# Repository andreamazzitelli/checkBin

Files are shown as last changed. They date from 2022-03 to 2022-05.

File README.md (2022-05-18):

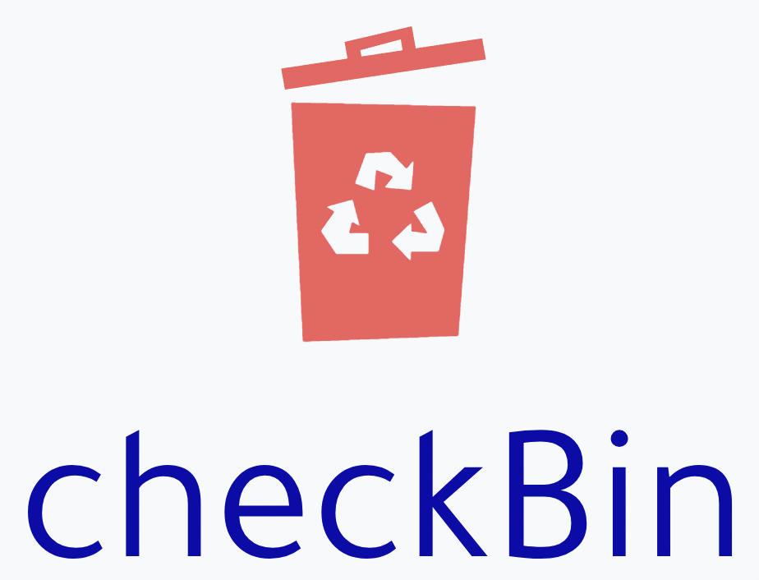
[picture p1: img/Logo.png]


## Group Members:

- Alessandro Marzilli - [LinkedIn Profile](https://www.linkedin.com/in/alessandro-marzilli-84a07a235/)
- Andrea Mazzitelli - [LinkedIn Profile](https://www.linkedin.com/in/andrea-mazzitelli-795ab4234/)
- Andrea Rodriguez - [LinkedIn Profile](https://www.linkedin.com/in/andrea-rod/)

## Description of the Project:

Today a big issue in many cities is garbage management, not only from an aesthetical point of view but also regarding administration and logistics costs. For this reason we envisioned a network of smart bins that monitor the fill level and give updates on their status. In this way the garbage pickup companies can have an overall view of the real-time situation and act accordingly. They could plan efficient pickup routes based on the fill level of the bins, manage the number of bins in each area and base their decisions on statistical analysis of provided data. As a consequence not only the company’s resources are used in a more efficient way but also the urban welfare increases thanks to less garbage on the streets and increased usability of the bins.

## Prototype:
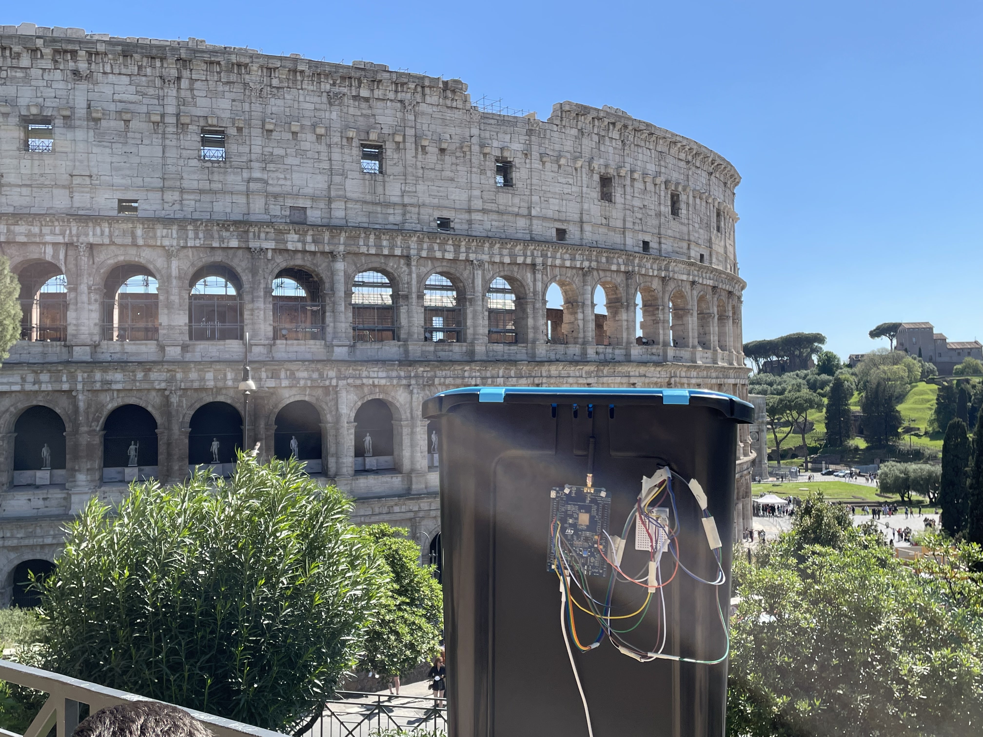
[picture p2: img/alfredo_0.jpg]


## Blogpost:
- [Link to hackster](https://www.hackster.io/463097/checkbin-439d2e)

## Documents:
### Third delivery:
- [Concept](/doc/Third%20Delivery/Concept.md)
- [Technology](/doc/Third%20Delivery/Technology.md)
- [Evaluation](/doc/Third%20Delivery/Evaluation.md)
### Second delivery:
- [2nd Delivery](/doc/Second%20Delivery/2ndDelivery.md)
- [Concept](/doc/Second%20Delivery/Concept.md)
- [Technology](/doc/Second%20Delivery/Technology.md)
- [Evaluation](/doc/Second%20Delivery/Evaluation.md)
### First delivery:
- [Concept](/doc/First%20Delivery/Concept.md)
- [Technology](/doc/First%20Delivery/Technology.md)
- [Evaluation](/doc/First%20Delivery/Evaluation.md)

## Videos:
### Third delivery:
- [Presentation of the project](https://youtu.be/aXUBlsJxcLs)
- [Demonstration of the project](https://youtu.be/RxiEFSnZMP0)
### Second delivery:
- [Technical details](https://youtu.be/C8MtbwdandU)
- [Evaluation](https://www.youtube.com/watch?v=46vqiiF-4S0)
- [Future plans](https://www.youtube.com/watch?v=kTAaOJ-Nj90)
### First delivery:
- [Concept](https://youtu.be/G0L1xYLjtnY)
- [Technology](https://youtu.be/uhQEX0K4BaE)
- [Evaluation](https://youtu.be/skyZr8n79Us)

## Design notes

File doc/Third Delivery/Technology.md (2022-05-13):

# TECHNOLOGY

## General Architecture

The computation is carried both on the edge and in the cloud. Every board will compute the fill level through the data coming in from the sensors and will send only this refined value to the cloud when it changes. The cloud will generate a dashboard with a map of the city combining the data received together with the database which links every bin identifier to its location. This dashboard will be publicly available through http both to the garbage collection company and to the citizens.

## Bin Overview

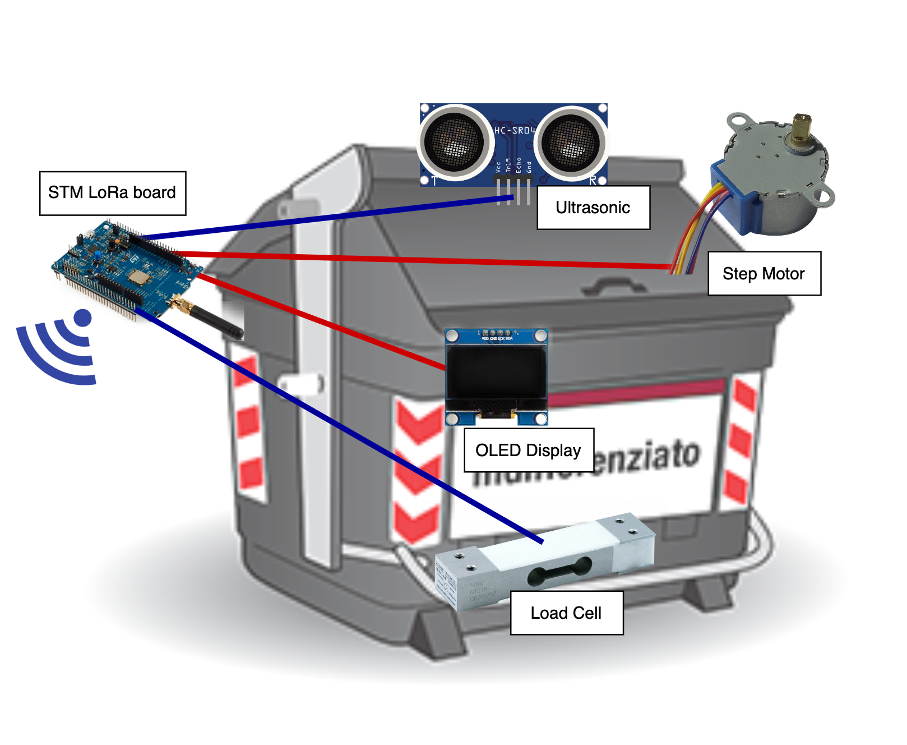
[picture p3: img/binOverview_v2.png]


Every smart bin is equipped with:

***LoRaWAN compatible STM board***

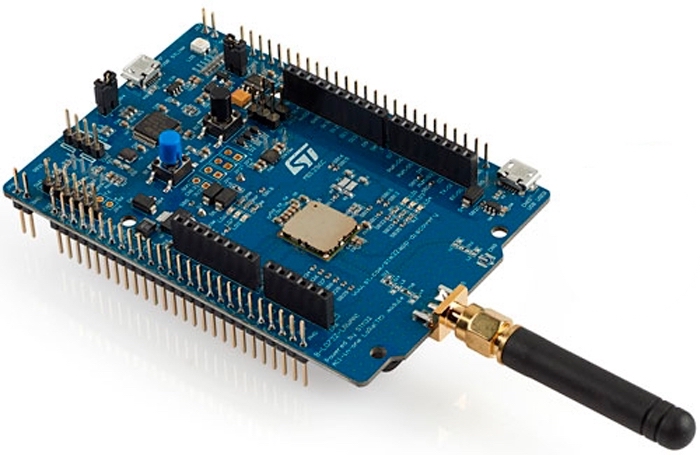
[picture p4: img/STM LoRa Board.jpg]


STM32L0 Discovery kit LoRa, Sigfox, low-power wireless. The module is powered by an STM32L072CZ microcontroller and SX1276 transceiver. The transceiver features the LoRa long-range modem, providing ultra-long-range spread-spectrum communication and high interference immunity, minimizing current consumption.
In the cities there should be some LoRaWAN gateways to pick up all the signals sent by the bins.
We used LoRa as communication protocol between the Smart bins and TheThingsNetwork. Using the integration between TheThingsNetwork and AWS IoTCore we receive the messages in the broker provided by AWS.
To allow the communication the following parameters must be set in the main.h file: dev_eui, app_eui, app_key. 

***Ultrasonic sensors*** to measure occupied volume in the bin.

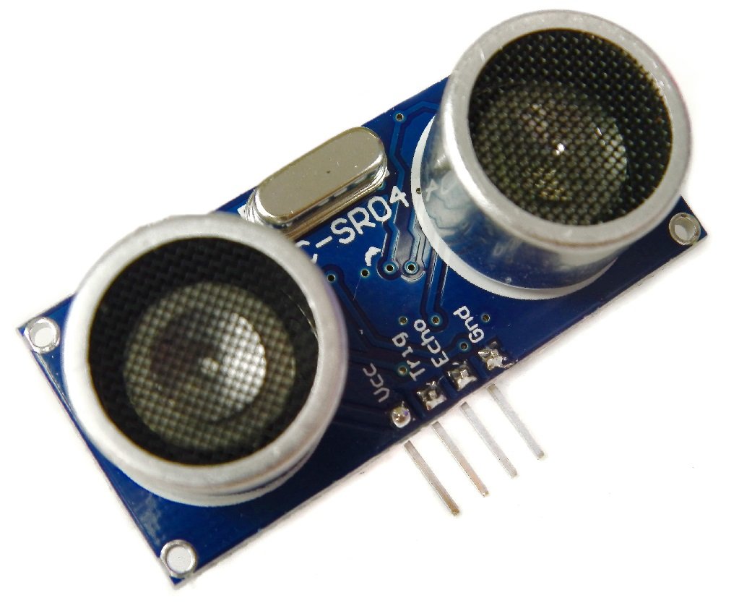
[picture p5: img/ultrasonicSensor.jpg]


We use ultrasonic sensors as the main way of measuring the fill level of the bins. In the prototype we used only one sensor but we decided to take three measures every time with a 30 seconds timeout. In this way we can discard measurements taken while the bin was open. Using more ultrasonic sensors would enhance the accuracy of the measures but implies a linear increase in the energy consumption of the sensors of the whole system.

***Load cells and a Load Cell Amplifier*** to measure the weight of the trash in the bin.

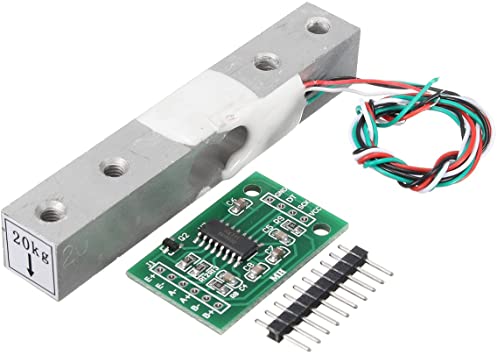
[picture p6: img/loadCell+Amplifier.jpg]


To detect anomalies in the data read by ultrasonic sensors we use a load cell. Together with statistics based on gathered data we can compare the occupied volume in the bin and the weight to understand if there is an anomaly in the ultrasonic measure. To estimate the weight based on the ultrasonic measure and to estimate the maximum weight, the following parameters must be set in the main.h file: height of the bin in cm, base area of the bin in square meters, waste type (plastic, metal, glass, paper, food, mixed).

To convert the value read from the load cell into grams we tested it using different weights. We then analyzed the measurements and discovered a linear pattern. Consequently, to convert the value returned from the load cell we must subtract it from the base value (8500 in our case) and divide it by 0.104.

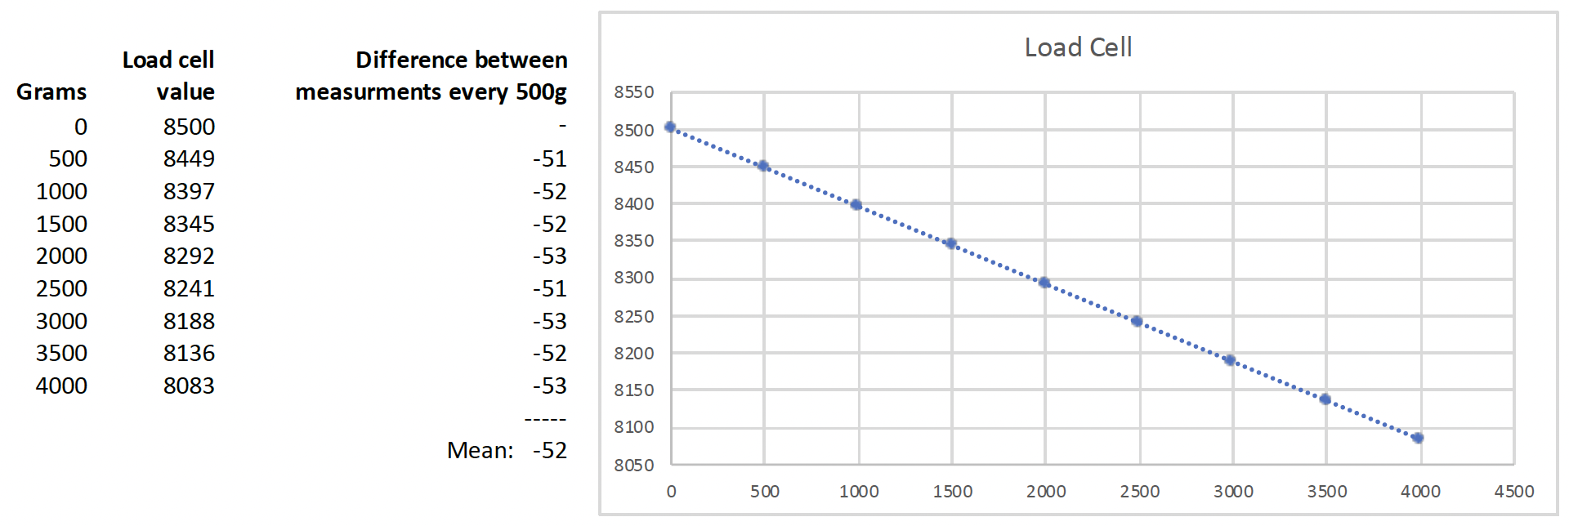
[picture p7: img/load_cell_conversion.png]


***Button*** to open the bin when it is locked.

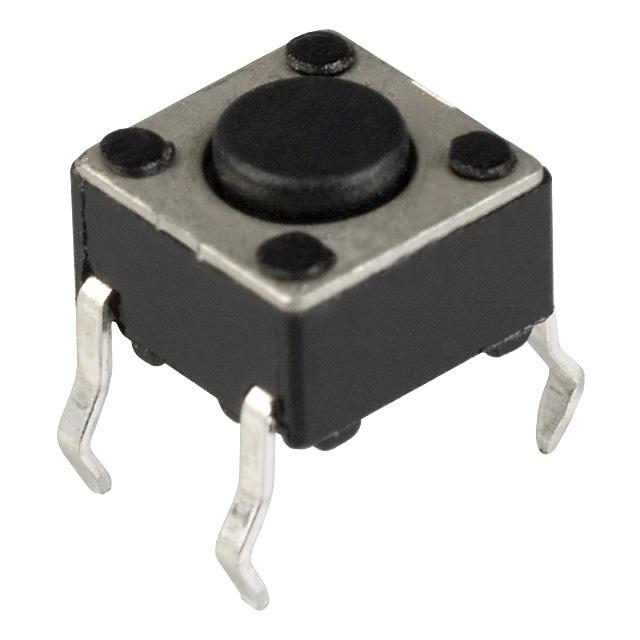
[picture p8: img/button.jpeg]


***OLED Display*** to show the fill level to the citizens.

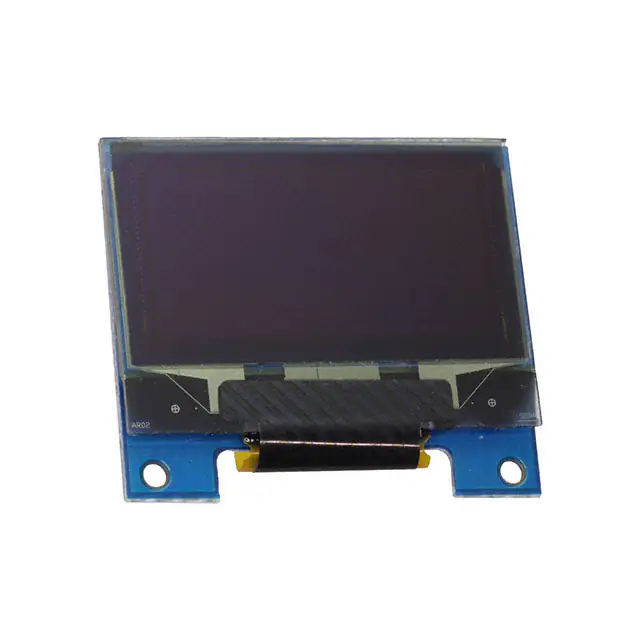
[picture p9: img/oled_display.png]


The OLED Display provides information about the fill level as feedback to the citizens. It shows a numeric value together with the progress bar. In this way they can be more involved in the process and take responsibility. 

***Stepper motor*** to lock the opening of the bin when it is full and to unlock it when it gets emptied.

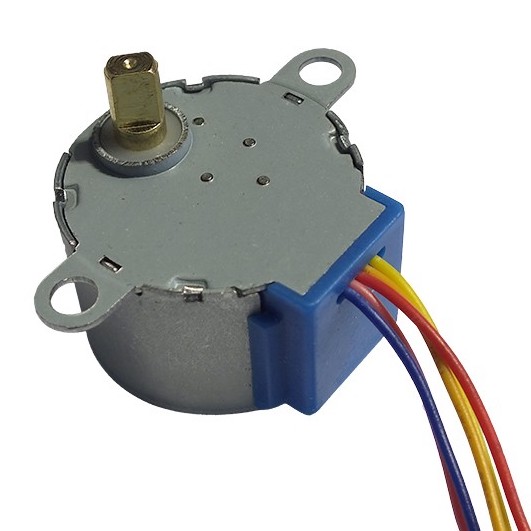
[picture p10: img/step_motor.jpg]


### All the components are wired following the diagram below:

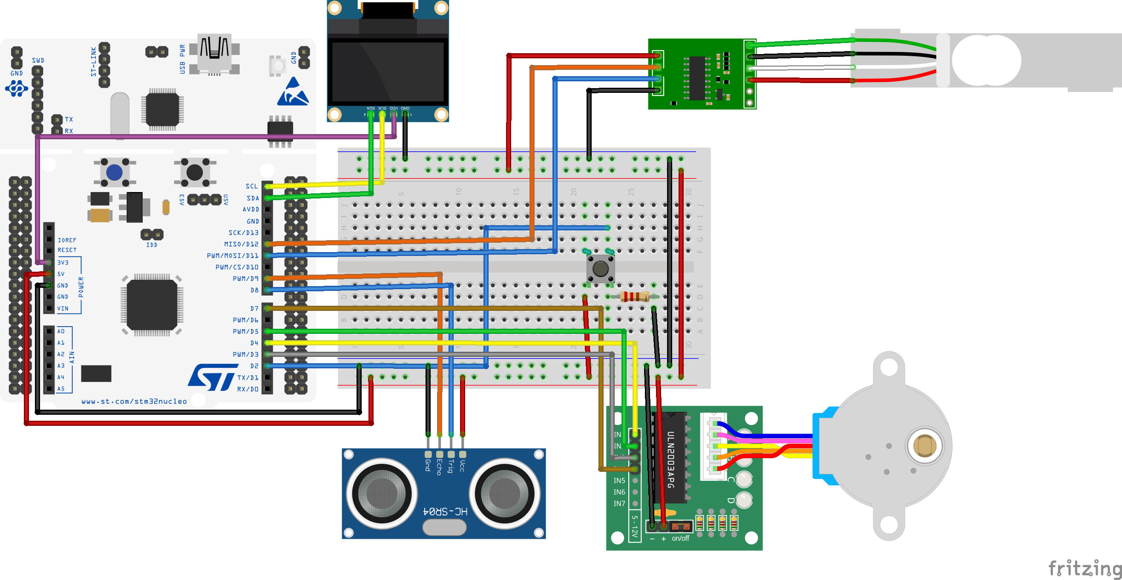
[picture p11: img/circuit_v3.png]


## The prototype

To see first hand how our system would be implemented on a real bin, we built a prototype. Starting from a standard bin we used hot glue and some 3D printed parts to put on the bin: sensors, actuators and the board.
We used a different kind of bin from the one shown in the overview. That is because of the unavailability of a standard garbage bin in this first development phase. However, the system we built is easily adaptable to different kinds of bins.
What you can see in these photos is the final result:

<div>
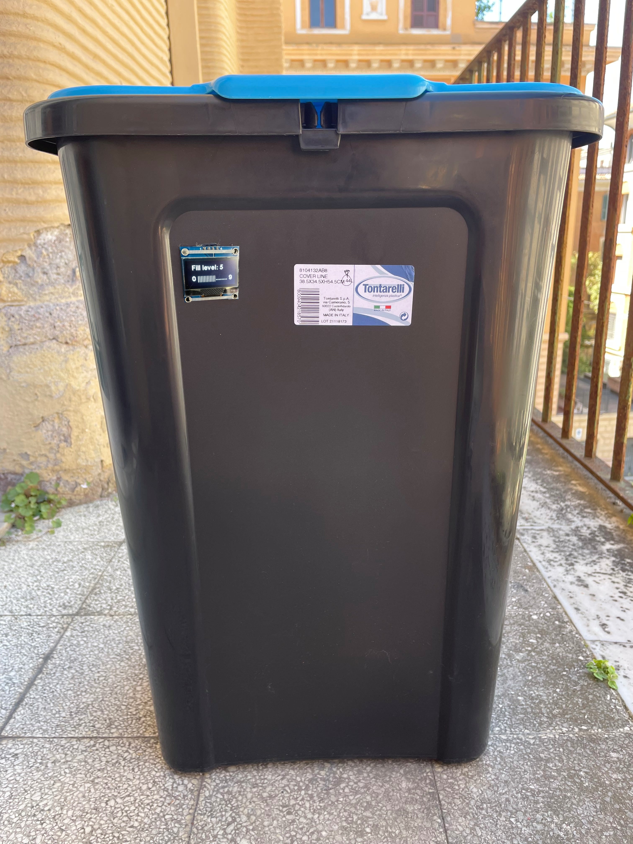
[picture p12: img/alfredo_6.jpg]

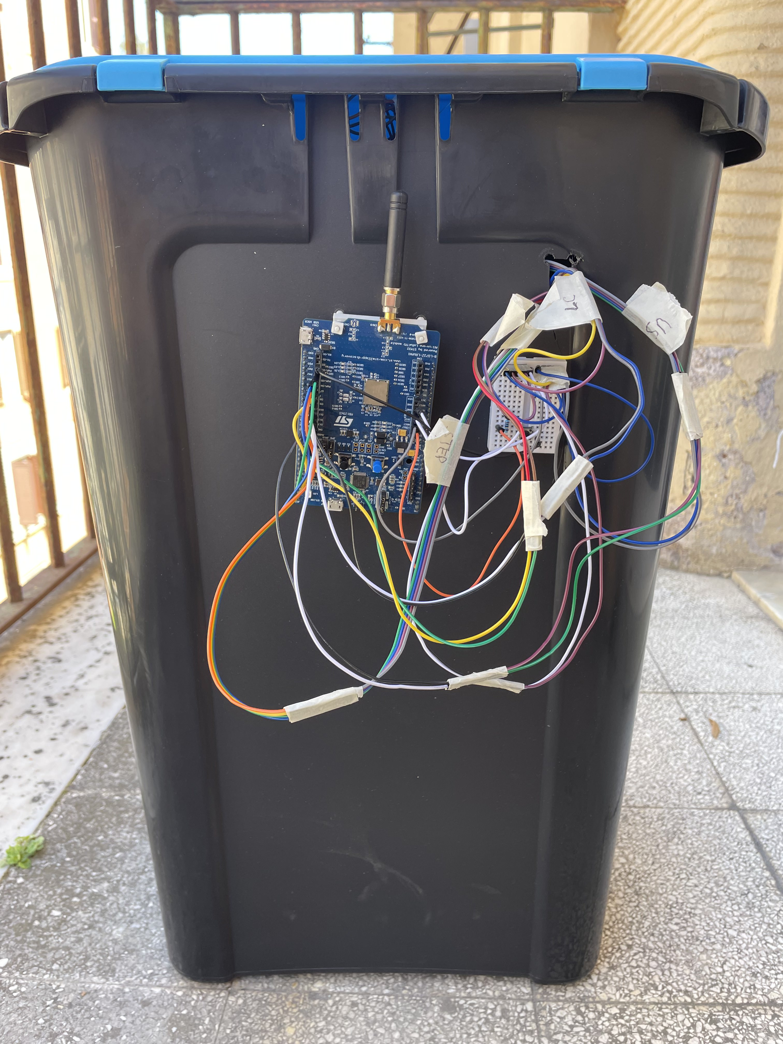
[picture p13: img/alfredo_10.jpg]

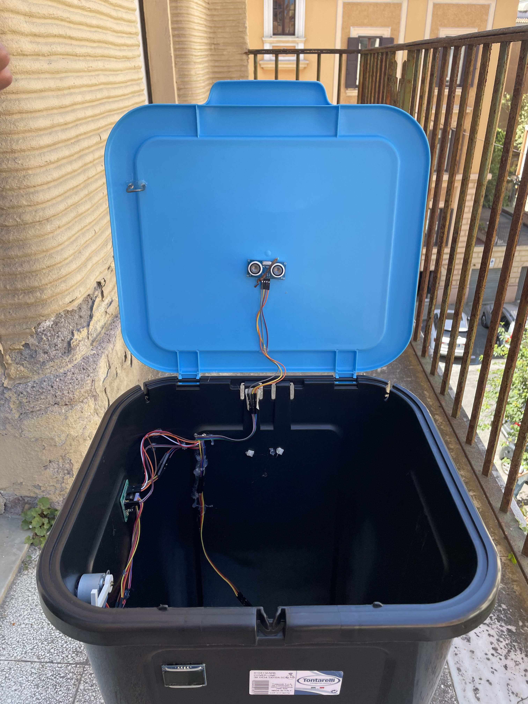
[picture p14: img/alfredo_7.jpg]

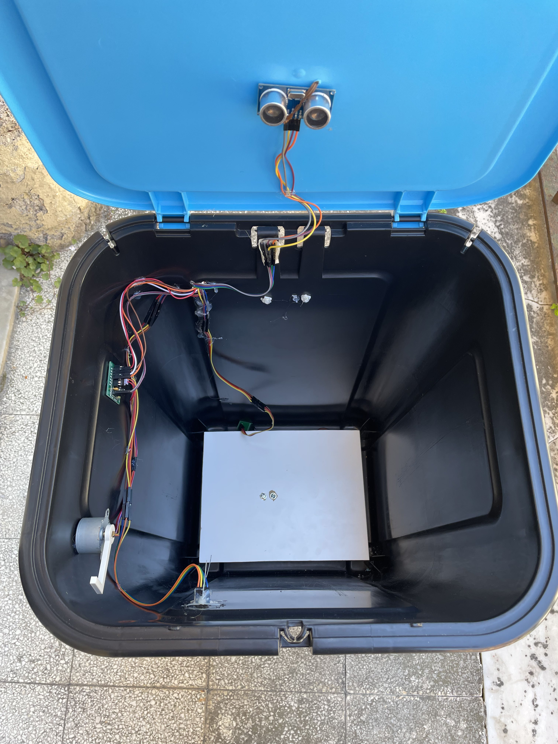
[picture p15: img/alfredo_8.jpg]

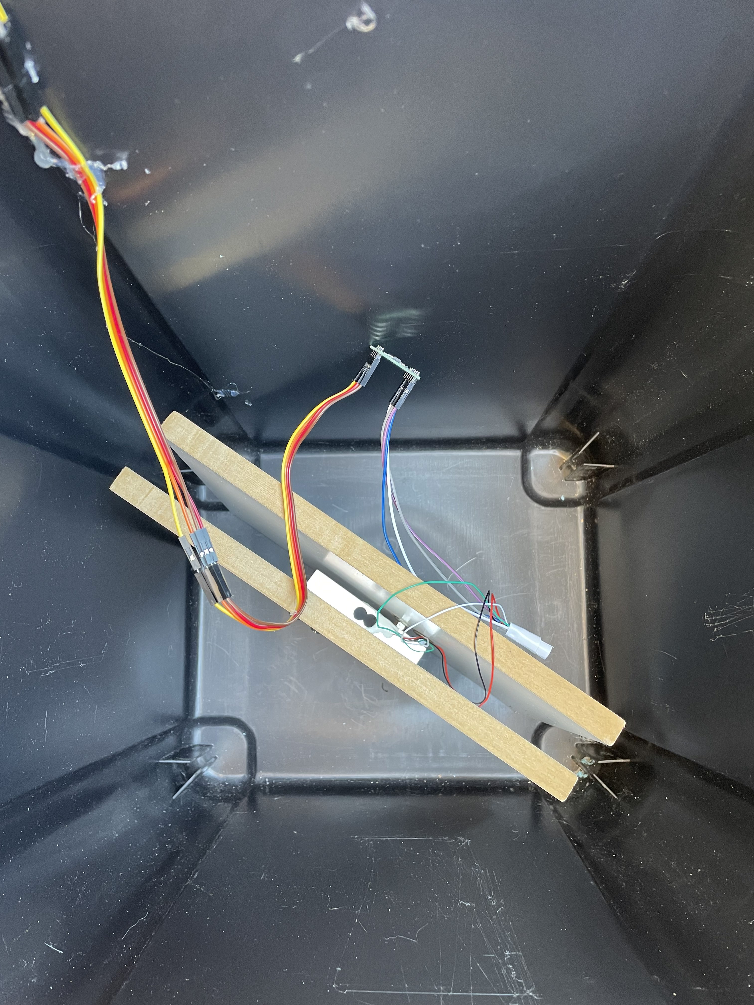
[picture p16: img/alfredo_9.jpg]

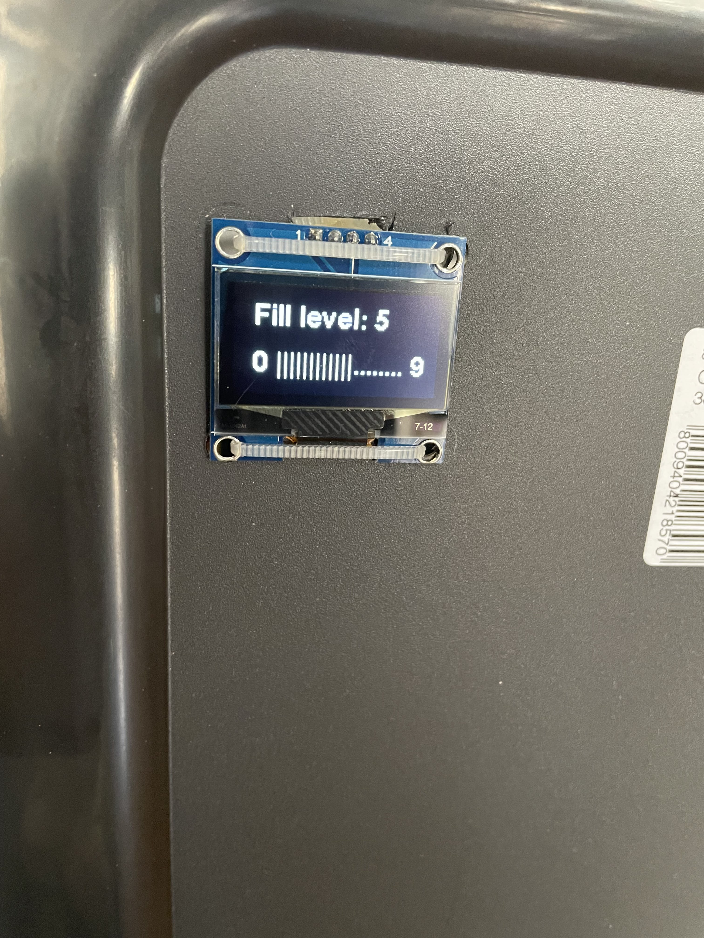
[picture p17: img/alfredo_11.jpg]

</div>

## Logic
The RIOT code implements the logical computation carried out in the LoRa board. In the main function it initializes the sensors, the actuators and the LoRa communication parameters.
It then starts a loop which alternates an active phase and a sleeping phase.

In the active phase the code does the following:
- the ultrasonic sensor makes three measurements with a 30 seconds timeout
- among the three values it rules out eventual anomalies and choose the pertinent one
- it then converts it to a fill level between 0 and 9 knowing the height of the bin
- the load cell is used to get the weight of the trash inside the bin
- based on the fill level and the type of garbage, it computes the estimated weight
- it also computes the maximum weight based on the height of the bin, the base area and the type of garbage

- if the fill level is lower than 8 but the weight is more than the maximum one (with a 20% margin) we have an anomaly; it sends to the cloud a fill level of 9 to notify the bin must be emptied but it does not close the bin.
- else if the fill level has changed from the previous measurements it sends the fill level to the cloud and updates the values on the OLED display. Then it also checks:
  - if the weight is below the estimated one (with a margin of 20%) when the fill level is greater or equal than 8; in that case it keeps the bin open
  - else if the fill level is greater or equal than 8 and the weight is coherent, it closes the bin
  - else it opens the bin

Moreover a separate thread is used to handle the bin’s opening using the button:
- if the button is pressed and the bin is locked then it is unlocked.

### Accuracy of the fill level
The fill level is computed from the measures taken by the ultrasonic sensor. Its accuracy can be an issue since the sensor measures the distance of a small area of the bin.
<br>As a consequence it could happen that in this area there is a lot of trash while the remaining space is empty. For this reason we decided to take into consideration also the weight measured through a load cell to implement a double check measure.
<br>Indeed we verify if the real weight measured is similar to the estimated weight with a margin of 20 percent (computed by using the fill level of the bin, the base area and the waste type). This double check allows us to detect a mismatch between the two measurements and makes us aware of any anomaly in the system.

- An anomaly is detected when the fill level is greater or equal than 8 and the weight is lower than the estimated one. We decided not to close the bin (since the bin could be not really full) while still sending the fill level to the cloud. Because of the mismatch between the measurements of the two sensors, we do not really know if the bin is actually full or not. Indeed we prefer to leave the bin open during an anomaly even if it is actually full instead of closing it while it is still empty.
- Another anomaly could happen if the load cell returns a weight greater than the maximum one (with a margin of 20 percent) but the fill level is smaller than 8. Also in this case we decided to adopt the same policy as before, keeping the bin open and sending 9 as fill level to the cloud. In this way an operator will empty the bin and solve the anomaly.

Another solution is to add more ultrasonic sensors to the system; this solution would increase the cost in terms of power consumption but it would be more precise in detecting the fill level of the bin.

## Network

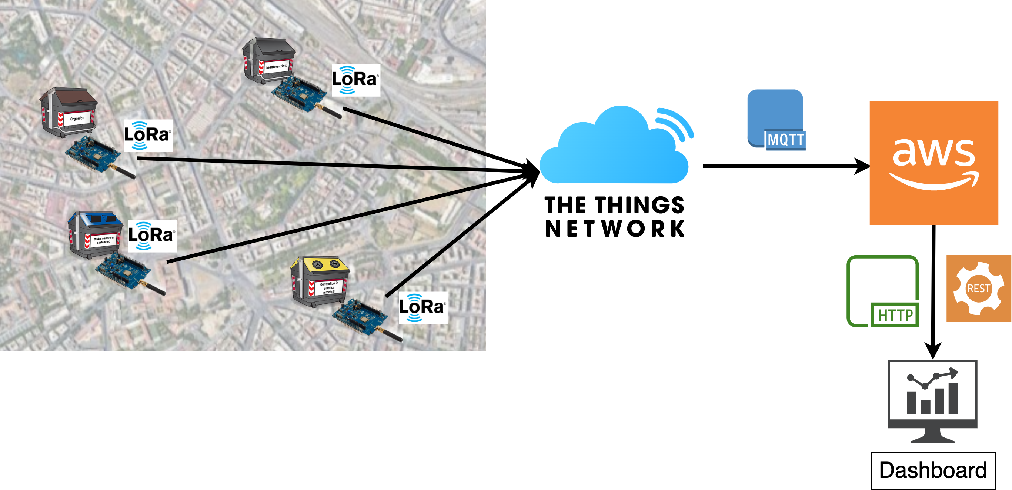
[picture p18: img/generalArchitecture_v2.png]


This architecture does not have any particular network constraint. We update the data on the cloud either when the fill level changes or when an anomaly is detected by the load cell. This choice has been made considering the nature of the system which only needs to know the last measured fill level.
We send to the cloud only the fill level of the bin, so the bandwidth needed by each device is minimal. Even though we take into account the great number of bins that even a small city has, the payload transmitted by each one is 1 byte every time the fill level changes (it should be no more than 10 times between two bin unloadings). Having planned a high update latency implies fewer usage of the radio that can be turned off during sleep times saving energy.

The security aspect is fulfilled by LoRa protocol which uses a double encryption to protect the payload from the source to the application server.

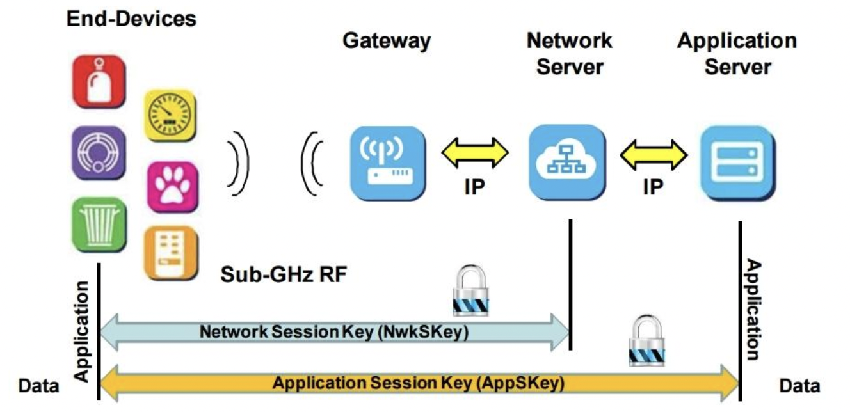
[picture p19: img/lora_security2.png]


*credits: https://riot-os.github.io/riot-course/slides/05-lorawan-with-riot/#12*

We ruled out every kind of communication directed to the board as it would need the radio always on. We couldn’t afford that in developing a battery powered device that needs to be up for at least a year without a constant power supply.
<br> We also considered structuring the network as a mesh to avoid the need of developing a gateway infrastructure. However, this approach would also require the radio to be always on but, as stated before, we cannot afford that.
<br> Different solutions must be researched to have a gateway infrastructure available. The garbage pickup company could develop its own infrastructure or it could use an existing infrastructure provided by some third party.

LoRa has been chosen as communication protocol because of its low power consumption and long range. Its main constraint is the low bitrate but it is still suitable for our project. WiFi and Bluetooth could provide higher bitrate but lower range, which is not ideal for our system. 3G/4G/5G could also provide not only higher bitrate and high range, but also an existing and wide gateway infrastructure. The main drawback of these technologies is the power consumption which is higher than the one we can support.

## Cloud

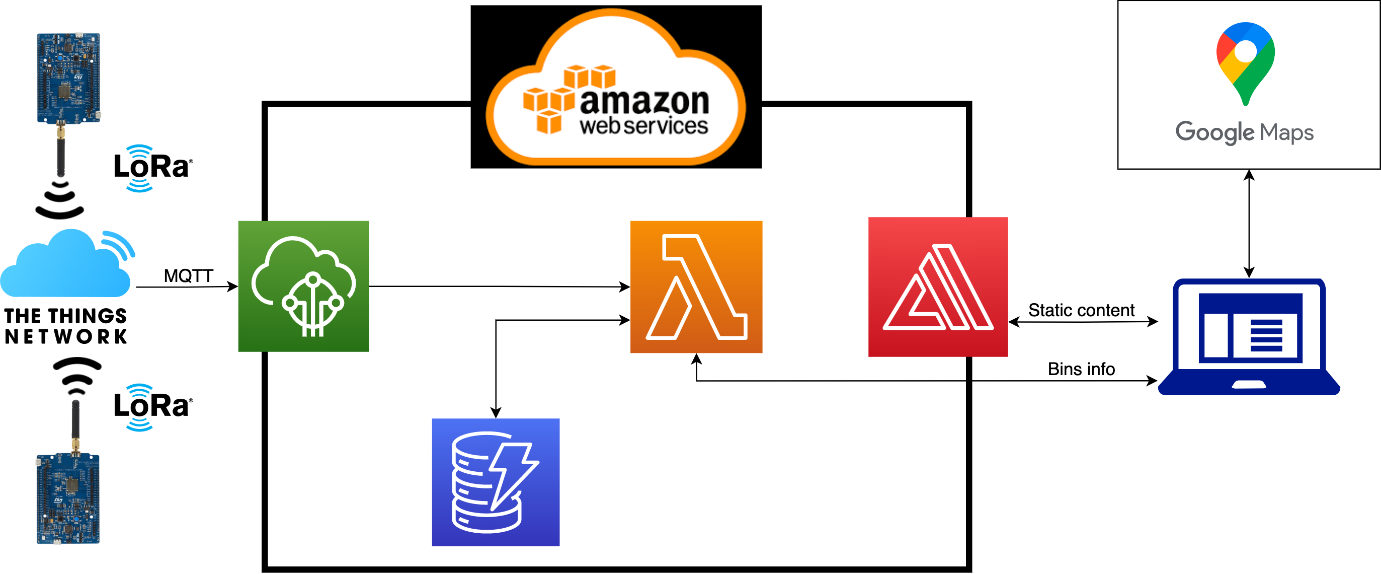
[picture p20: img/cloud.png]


The cloud part of the project is composed by the following elements:
- The Things Network
- AWS IoT Core
- AWS Lambda Function
- AWS DynamoDB
- AWS Amplify
- APIs provided by Google Maps.

The format of the messages sent from the board is the following: `fill_level`.

The DataBase is composed of a single table `binTable(DevEUI, id, lat, lng, last_fill_level, last_fill_timestamp)` in which:
- the DevEUI assigned to the device is used as primary key of the table; 
- id is used to identify the bin on the web dashboard;
- lat and lng are the geographic coordinates where the bin is located;
- last_fill_level is the last fill level received from the board;
- last_fill_timestamp is the timestamp at which the last fill level was received.

As the primary key of the table we decided to use the DevEUI assigned to each bin. In this way we can immediately associate the messages received to the respective bin using information that is automatically sent in the exchange, without the need to add more information in the message payload.
We also chose to use an ID to identify in a simpler way the bins in the web dashboard. Being the bins often one near the other, a garbage truck driver can use the ID to understand which bin needs to be emptied. Clearly, the id should be written on the physical bin. 

When a message containing the fill level is sent to a LoRa Gateway in The Things Networks (TTN), TTN relays the incoming message to the MQTT Broker in the AWS IoT Core.
Once the IoT Core receives a new message on the broker, using its Rule Engine, it calls the Lambda Function “writeBinTable_v2”. This function updates the tuple in the DB that has the DevEUI as the one in the message that just arrived.

The user interacts with AWS Amplify to get the static content. Once the page on the client browser completely loads, it runs the javascript code that generates the map with markers where bins are located. The user can now click a marker to see the bin id, the last fill level and the time when the last fill level was detected.
In particular, the js code does the following:
- it calls the Google Maps API to retrieve the map;
- it calls the Lambda function “getBin_v2” using the “Function URL” that returns all the tuples inside “binTable” ([here](https://docs.aws.amazon.com/lambda/latest/dg/lambda-urls.html) there is a description of what is a function URL);
- once the data arrives, for every bin the script adds a clickable marker containing all the info about the bin with a different color depending on the fill level;
- every 10 minutes the dashboards reloads, we chose not to update it in real time using websockets due to scalability concerns.

The web dashboard can be accessed [here](https://dev7723.d2wnn0xh1kb5op.amplifyapp.com/).

From the web interface the user can also add a new bin to the system by filling the latitude and longitude fields and clicking on the “Add Bin” button. It calls the function URL of the “addBin_v2” Lambda Function that creates a new tuple in “binTable” and returns to the user the new bin id.

Moreover the user can delete a bin from the system by inserting the id in the corresponding field and then clicking on the “Delete Bin” button. In this way the Lambda function “deleteBin” is called and the tuple associated with the specified bin’s id is deleted from the DB.

All the data stored in the database can also be reached via a REST API, to ease the integration with pre-existing management systems of the garbage pickup companies. You can call it from [here](https://slfosy6btrlq2u2xufldfoy5fi0reboc.lambda-url.us-east-1.on.aws/).

## Future plans for technology improvements:

### Edge computing
We could use the edge to run a machine learning algorithm which learn and adjust some relevant parameters like the interval between measurements or the specific weights of every waste type.
For both aspects we can consider different possibilities:
- using all global data coming from every bin, in this case gateways should be orchestrated to learn the global parameters. This option is the best one to learn the specific weights of waste types. Due to the facts that these parameters do not differs much among bins, using a global algorithm would allow us to have a bigger dataset that increases the accuracy of the model and produces better results.
- using all data received by a single gateway, in this way we would have neighbourhood specific parameters.
- using data coming from a single bin, in this way we would have specific parameters for every bin. This option is the best one to learn the interval between measurements. Indeed, regarding the fill rate and frequency of waste deliveries, each bin is mostly different from the others.

To achieve the proposed goals, edge computing is the best option because the boards do not have enough computational power or energy to run complex algorithms. Moreover the gateways already have the necessary data and can communicate with the boards to send the new parameters. Regarding a possible usage of the cloud, the measure interval is a parameter strictly related to a bin and it would not make sense sending parameters to the cloud to compute as there's no need to aggregate data.

### Replacing the OLED with a e-ink display

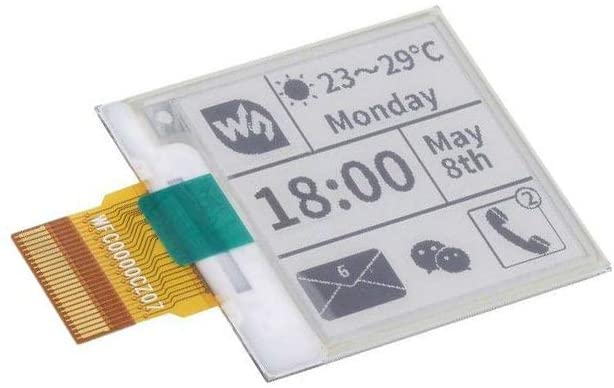
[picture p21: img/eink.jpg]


To further reduce the energy consumption we could replace the OLED with a e-ink display. This kind of displays consumes a relevant amount of energy only when the values are updated. Indeed, during standby their energy consumption is negligible.
Taking into account the update frequency of the display in our system, the e-ink option could be more appropriate.

### Charging methods
We could add a solar panel to reduce the size of the needed battery and increase the lifetime. We would not have any problem finding the space to add the panel due to the size of standard bins. More details in the evaluation document.

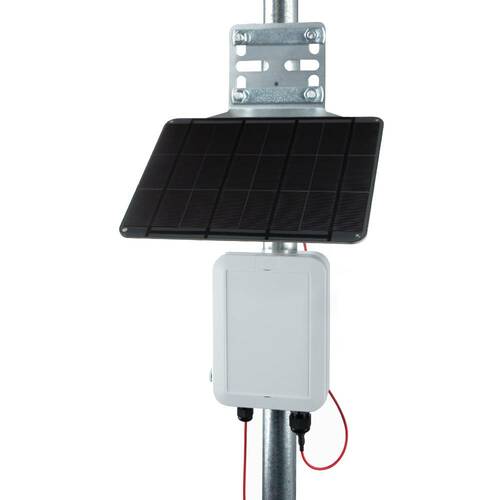
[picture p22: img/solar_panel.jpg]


A different option would be using the energy provided by users pressing on the pedal to open the bin. This mechanical energy could be converted into electric energy using a dynamo. However, even if the frequency of this action is considerably high, the energy produced every time would not be able to support the consumption of the whole system.

### Link to previous version: [Technology - Second delivery](../Second%20Delivery/Technology.md)

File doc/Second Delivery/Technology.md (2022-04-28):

# TECHNOLOGY

## General Architecture

The computation is carried both on the edge and in the cloud. Every board will compute the fill level through the data coming in from the sensors and will send only this refined value to the cloud when it changes. The cloud will generate a dashboard with a map of the city combining the data received together with the database which links every bin identifier to its location. This dashboard will be publicly available through http both to the garbage collection company and to the citizens.

## Bin Overview



Every smart bin is equipped with:

***LoRaWAN compatible STM board***



STM32L0 Discovery kit LoRa, Sigfox, low-power wireless. The module is powered by an STM32L072CZ microcontroller and SX1276 transceiver. The transceiver features the LoRa long-range modem, providing ultra-long-range spread-spectrum communication and high interference immunity, minimizing current consumption.
In the cities there should be some LoRaWAN gateways to pick up all the signals sent by the bins.
We plan to use LoRa as communication protocol between the Smart bins and TheThingsNetwork. Using the integration between TheThingsNetwork and AWS IoTCore we’ll receive the messages in the broker provided by AWS.
To allow the communication the following parameters must be set in the main.h file: dev_eui, app_eui, app_key. There should also be set the bin identifier which will be linked to its position in the database.

***Ultrasonic sensors*** to measure occupied volume in the bin.



We use ultrasonic sensors as the main way of measuring the fill level of the bins. In the prototype we used only one sensor but we decided to take three measures every time with a 30 seconds timeout. In this way we can discard measurements taken while the bin was open. Using more ultrasonic sensors would enhance the accuracy of the measures but implies a linear increase in the energy consumption of the sensors of the whole system.

***Load cells and a Load Cell Amplifier*** to measure the weight of the trash in the bin.



To detect anomalies in the data read by ultrasonic sensors we use a load cell. Together with statistics based on gathered data we can compare the occupied volume in the bin and the weight to understand if there is an anomaly in the ultrasonic measure. To estimate the weight based on the ultrasonic measure and to estimate the maximum weight, the following parameters must be set in the main.h file: height of the bin in cm, base area of the bin in square meters, waste type (plastic, metal, glass, paper, food, mixed).

To convert the value read from the load cell into grams we tested it using different weights. We then analyzed the measurements and discovered a linear pattern. Consequently to convert the value returned from the load cell we must subtract it from the base value (8500 in our case) and divide it by 0.104.



***OLED Display*** to show the fill level to the citizens.



The OLED Display will provide information about the fill level as feedback to the citizens. In this way they can be more involved in the process and take responsibility.

***Stepper motor*** to lock the opening of the bin when it is full and to unlock it when it gets emptied.



### All the components are wired following the diagram below:

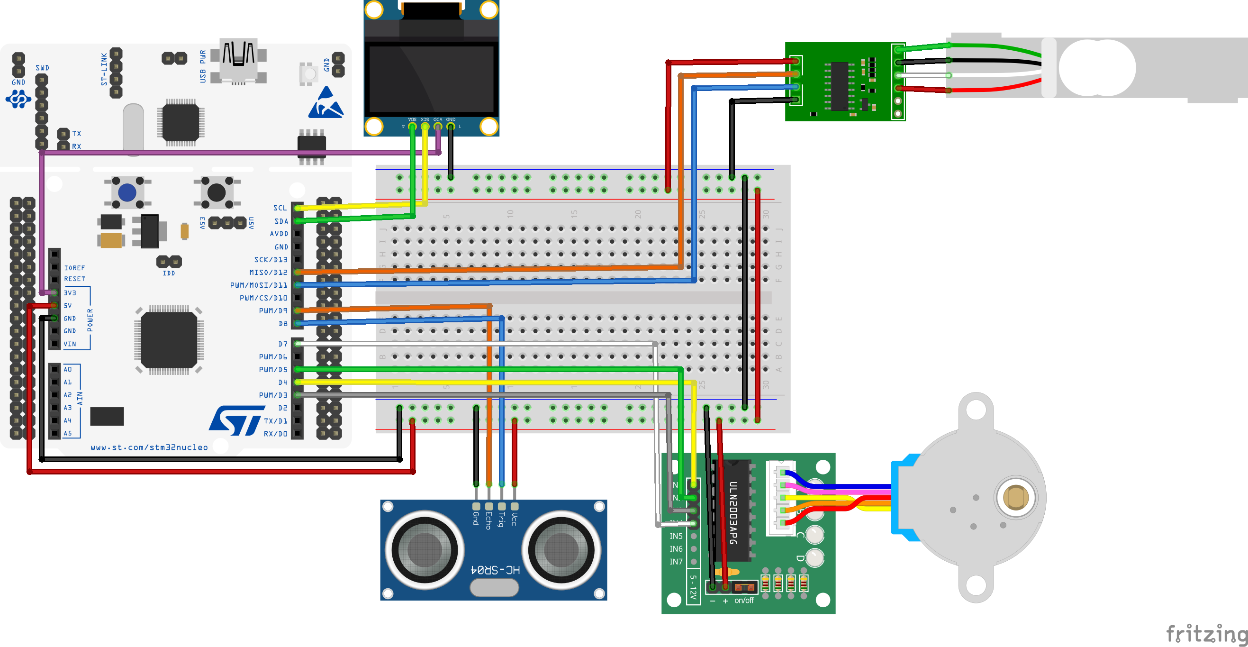
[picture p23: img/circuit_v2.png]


## Logic
The RIOT code implements the logical computation carried out in the LoRa board. In the main function it intializes the sensors, the actuators and the LoRa communication parameters.
It then starts a loop which alternates an active phase and a sleeping phase.

In the active phase the code does the following:
- the ultrasonic sensor makes three measurments with a 30 seconds timeout
- among the three values it rules out eventual anomalies and choose the pertinent one
- it then converts it to a fill level between 0 and 9 knowing the height of the bin
- the load cell is used to get the weight of the trash inside the bin
- based on the fill level and the type of garbage, it computes the estimated weight
- it also computes the maximum weight based on the height of the bin, the base area and the type of garbage

- if the fill level is lower than 8 but the weight is more than the maximum one (with a 20% margin) we have an anomaly; it sends to the cloud a fill level of 9 to notify the bin must be emptied but it does not close the bin.
- else if the fill level has changed from the previous measurments it sends the fill level to the cloud and updates the value on the OLED display. Then it also checks:
  - if the weight is below the estimated one (with a margin of 20%) when the fill level is greater or equal than 8; in that case it keeps the bin open
  - else if the fill level is grater or equal than 8 and the weight is coherent, it closes the bin
  - else it opens the bin

### Accuracy of the fill level
The fill level is computed from the measures taken by the ultrasonic sensor. Its accuracy can be an issue since the sensor measures the distance of a small area of the bin.
<br>As a consequence it could happen that in this area there is a lot of trash while the remaining space is empty. For this reason we decided to take into consideration also the weight measured through a load cell to implement a double check measure.
<br>Indeed we verify if the real weight measured is similar to the estimated weight with a margin of 20 percent (computed by using the fill level of the bin, the base area and the waste type). This double check allows us to detect a mismatch between the two measurements and makes us aware of any anomaly in the system.

- An anomaly is detected when the fill level is greater or equal than 8 and the weight is lower than the estimated one. We decided not to close the bin (since the bin could be not really full) while still sending the fill level to the cloud. Because of the mismatch between the measurements of the two sensors, we do not really know if the bin is actually full or not. Indeed we prefer to leave the bin open during an anomaly even if it is actually full instead of closing it while it is still empty.
- Another anomaly could happen if the load cell returns a weight greater than the maximum one (with a margin of 20 percent) but the fill level is smaller than 8. Also in this case we decided to adopt the same policy as before, keeping the bin open and sending 9 as fill level to the cloud. In this way an operator will empty the bin and solve the anomaly.

Another solution is to add more ultrasonic sensors to the system; this solution would increase the cost in terms of power consumption but it would be more precise in detecting the fill level of the bin.

## Network



This architecture does not have any particular network constraint. We plan to update the data on the cloud either when the fill level changes or when an anomaly is detected by the load cell. This choice has been made considering the nature of the system which only needs to know the last measured fill level.
We’ll send to the cloud only the fill level of the bin and its identifier, so the bandwidth needed by each device is minimal. Even though we take into account the great number of bins that even a small city has, the payload transmitted by each one is less than 10 bytes every time the fill level changes (it should be no more than 10 times between two bin unloadings). Having planned a high update latency implies fewer usage of the radio that can be turned off during sleep times saving energy.

We ruled out every kind of communication directed to the board as it would need the radio always on. We couldn’t afford that in developing a battery powered device that needs to be up for at least a year without a constant power supply.
<br> We also considered structuring the network as a mesh to avoid the need of developing a gateway infrastructure. However, this approach would also require the radio to be always on but, as stated before, we cannot afford that.
<br> Different solutions must be researched to have a gateway infrastructure available. The garbage pickup company could develop its own infrastructure or it could use an existing infrastructure provided by some third party.

LoRa has been chosen as communication protocol because of its low power consumption and long range. Its main constraint is the low bitrate but it is still suitable for our project. WiFi and Bluetooth could provide higher bitrate but lower range, which is not ideal for our system. 3G/4G/5G could also provide not only higher bitrate and high range, but also an existing and wide gateway infrastructure. The main drawback of these technologies is the power consumption which is higher than the one we can support.

## Cloud



The cloud part of the project is composed by the following elements:
- The Things Network
- AWS IoT Core
- AWS Lambda Function
- AWS DynamoDB
- AWS Amplify
- APIs provided by google maps.

The format of the messages sent from the board is the following: `bin_id | fill_level`.

The DataBase is composed of a single table `bin_table(id, lat, lng, last_fill_level, last_fill_timestamp)` in which:
- id is the bin id;
- lat and lng are the geographic coordinates where the bin is located;
- last_fill_level is the last fill level received from the board;
- last_fill_timestamp is the timestamp at which the last fill level was received.

A message containing the bin id and fill level is sent to a LoRa Gateway in The Things Networks (TTN). Then TTN relays the incoming message to the MQTT Broker in the AWS IoT Core.
Once the IoT Core receives a new message on the broker, using its Rule Engine, it calls the Lambda Function “writeBinTable”. This function updates the tuple in the DB that has the same id as the one in the message that just arrived.

The user interacts with AWS Amplify to get the static content. Once the page on the client browser completely loads, it runs the javascript code that generates the map with markers where bins are located. The user can now click a marker to see the bin id, the last fill level and the time when the last fill level was detected.
In particular, the js code does the following:
- it calls the Google Maps API to retrieve the map;
- it calls the Lambda function “getBin” using the “Function URL” that returns all the tuples inside “bin_table” ([here](https://docs.aws.amazon.com/lambda/latest/dg/lambda-urls.html) there is a description of what is a function URL);
- once the data arrives, for every bin the script adds a clickable marker containing all the info about the bin with a different color depending on the fill level. 

From the web interface the user can also add a new bin to the system by filling the latitude and longitude fields and clicking on the “Add Bin” button. It calls the function URL of the “addBin” Lambda Function that creates a new tuple in “bin_table” and returns to the user the new bin id.

All the data stored in the database can also be reached via a REST API, to ease the integration with pre-existing management systems of the garbage pickup companies. You can call it from [here](https://slfosy6btrlq2u2xufldfoy5fi0reboc.lambda-url.us-east-1.on.aws/).

### Link to previous version: [Technology - First delivery](../First%20Delivery/Technology.md)

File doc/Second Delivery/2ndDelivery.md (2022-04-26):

# 2nd delivery

## Addressing the comments received during the 1st delivery:
During the first delivery we received the following main comments:
1. What are the requirements? As low as possible is not a requirement.
2. Do you expect a sampling every second, hour or what?
3. Accuracy of fill level can be an issue.
4. Precision and recall.

And we address them in the following way:
1. We decided a lower bound for the battery replacement, it should last no less than a year. In this way the price of the logistics to replace the batteries would not impact the company’s balance sheet. To achieve this goal we’ll measure more in detail the power consumption of our system and we’ll experiment with charging methods.
2. We performed a study on the sampling rate, discussing several possibilities. In particular, we analyzed the following ones: 
  - continuous sampling: gives us the best feedback but it is expensive in terms of energy cost.
  - continuous sampling of one sensor and sample on the other when needed: surely a better solution than the previous one. If we keep ON only the sensor that consumes less energy and use the other to check for correctness, we can achieve good feedback from the device while reducing the energy consumption with regard to the previous case.
  - periodic sensing: is the solution that we went for. It allows us to tailor a duty cycle that gives good enough feedback, while keeping an energy consumption that fits our needs.
<br><br>This is a brief overview of the analysis, the complete one can be found in the Evaluation document.

3. To address issues in the accuracy of the fill level, we implemented a double check measurement which let us detect anomalies in the system. Indeed we also use a load cell which returns the real weight. This measurement is then compared with the estimated one computed using the fill level, the base area and the waste type. More details can be found in the Technology document.

4. We performed tests and measurements using our prototype to analyze the frequency of errors and anomalies. The gathered data can be found in the Evaluation document.

## Changes in the architecture: 
- Servo Motor → Step Motor: we made this change due to a limitation of the RIOT OS software. Indeed, RIOT does not implement the PWM Interface for our board b-l072z-lrwan1. So we decided to use the step motor that only requires the basic gpio.

- LCD Monitor → OLED Display: we made this change because the LCD monitor we have available uses 12 pins but the chosen board (b-l072z-lrwan1) doesn’t have enough. The OLED display we went for requires only 4 pins, so we could fit it in the pins schematics.

## Technical work:
Since the last delivery the following things were done:
- we built a prototype;
- we developed the code for the board;
- we configured the connection between the board and The Things Network;
- we defined with more precision which AWS services to use and how they interact with each other, also developing the code running on the cloud;
- we developed the web interface;

### Prototype Build:
We used a different kind of bin from the one shown in the overview of the project. That is because of the unavailability of a standard garbage bin in this first development phase. However, the system we built is easily adaptable to different kinds of bins. We built the following prototype:

<div>
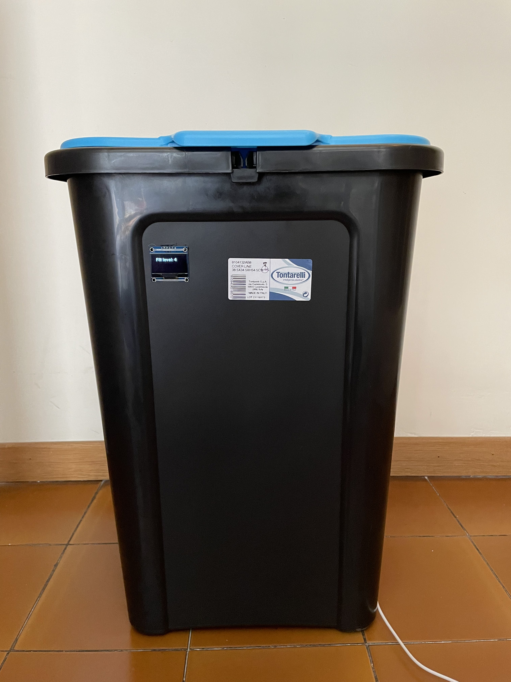
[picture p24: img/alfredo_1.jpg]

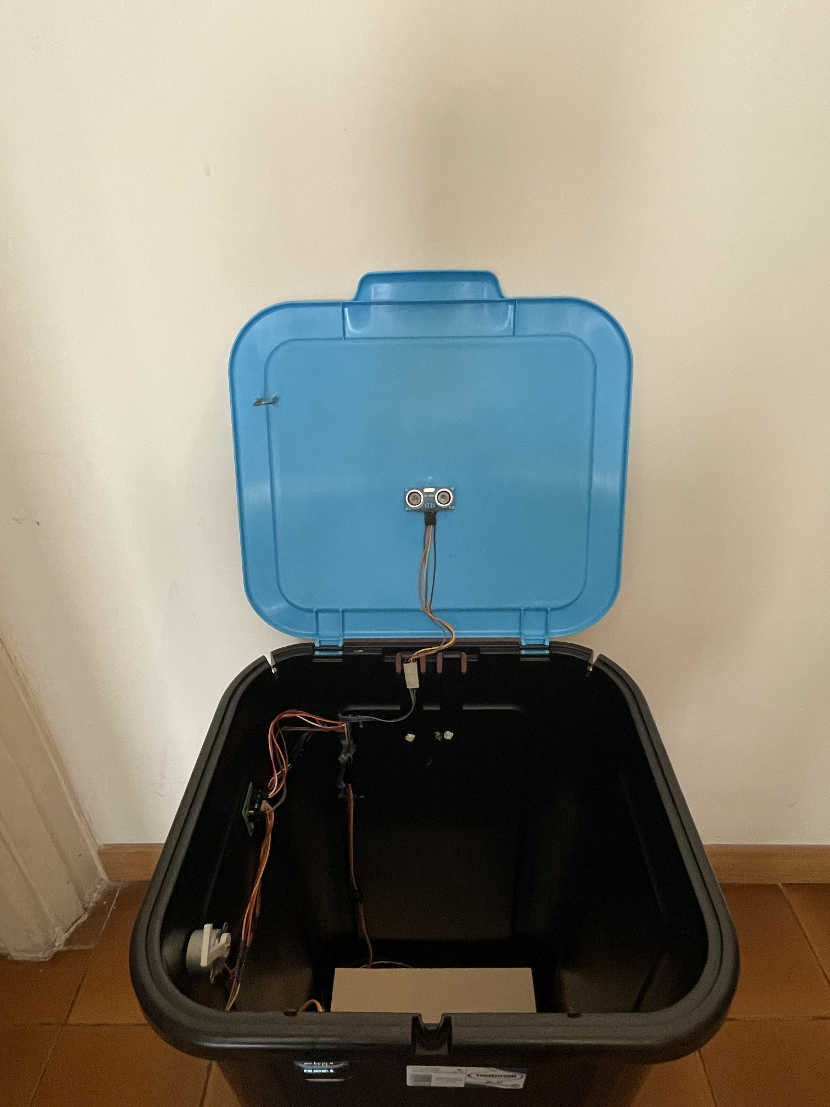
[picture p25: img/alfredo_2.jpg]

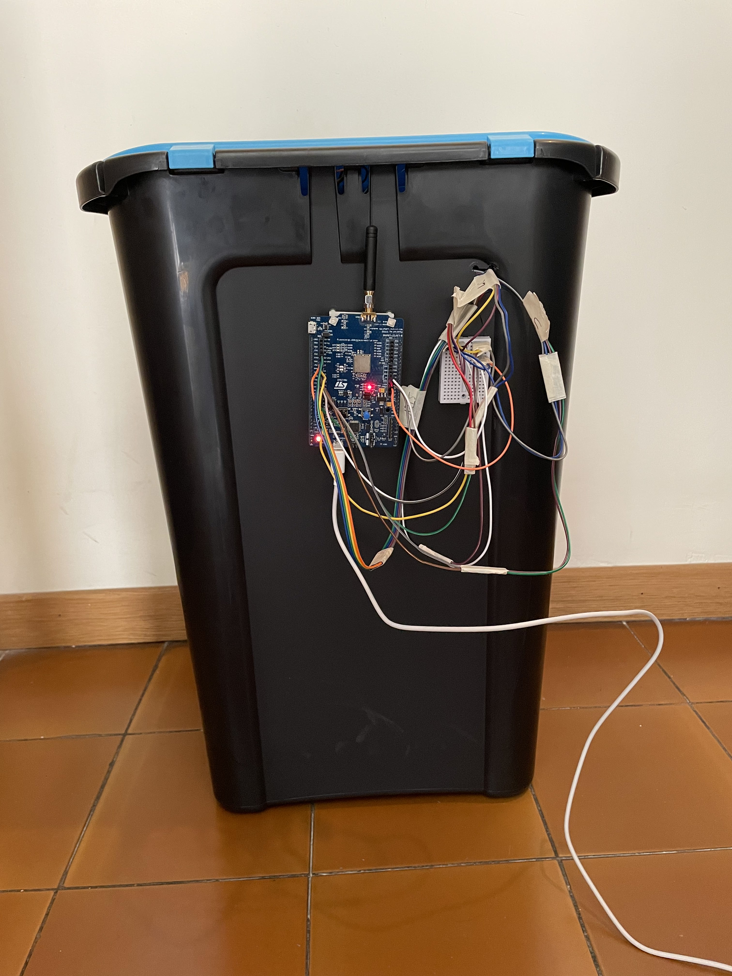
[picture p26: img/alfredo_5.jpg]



</div>

### Code on the Board:
Since the last delivery we wrote the necessary functions to:
- read values from the sensors;
- act using the actuators;
- send data using LoRa;

Moreover we wrote all the logic that governs the system using the above functions. More details about this aspect can be found in the Technology Document.

### AWS:
We defined what AWS services to use. We chose:
- AWS IoT Core: to receive data from The Things Network and invoke a Lambda function;
- AWS Lambda: to implement the functions needed to interact with the database;
- AWS DynamoDB: to store the data and easily have access;
- AWS Amplify: to host the static content of the web interface and make it easily accessible.

### Web Interface:
We developed the web interface to show the user a map with markers and fill levels, also allowing him to add new bins.



You can find the web interface [here](https://dev7723.d2wnn0xh1kb5op.amplifyapp.com).

## Plans for 3rd delivery:
- Better evaluation on energy consumption, also to adjust the duty cycle on our needs.
- Try different charging methods if needed.
- Web socket implementation to update the fill levels on the dashboard in real time.
- Better statistics on the specific weight for each waste type, based on tests.
- New button in the dashboard to delete a bin, given its identifier.
- Show the fill level as a progress bar on the oled display.
- Add a button or an NFC reader (if the energy consumption does not affect the battery lifetime) to open the bin when it is going to be emptied.
- Consider the possibility of using as bin identifier the DEV_EUI assigned to the board for the LoRa communication, removing the bin identifier in the message sent from the board to the cloud.
- Study the power management API of RIOTos to understand if it can be useful for our purposes.
- Implement security aspects of the communication from the board to the cloud.

## Evaluation conducted since the 1st delivery:
We performed the following evaluation:
- we analyzed in more detail the energy consumption of our system;
- we analyzed different possibilities for the sampling frequency and the radio usage, to choose the strategy that suits our application best;
- we measured the sensors’ precision;
- we conducted some tests to evaluate the accuracy of the system;
- we briefly discussed network aspects of the system, such as network usage and latency.

## Next evaluation phase:
We will focus more on energy consumption, which is a key aspect for our system. We will take more accurate measures using our prototype in different settings. Specifically, we are going to measure the following parameters:
- Energy consumption during wake-up time
- Energy consumption to activate the sensors and compute the fill level
- Energy consumption to transmit data using LoRa
- Energy consumption during sleep mode
- Energy consumption of the OLED display (to understand if it can be used in our system, given the battery constraints)

We will also evaluate different charging methods to find out if there exists a viable option.

Regarding the network we do have strict constraints given by the chosen technology. The main one is on the size of the packets but it does not affect our application. However, to confirm this statement we are going to measure:
- Total size of LoRa packets
- Total size of the payloads
- Total latency from the beginning of the measuring phase to the update of the web dashboard

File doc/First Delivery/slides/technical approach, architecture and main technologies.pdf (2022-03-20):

## checkBin - Technology


General Architecture

Bin - Overview


Bin - Circuit Detail

Servo Motor | Load Cell

HX711 Load Cell
Amplifier

LCD Monitor

Ultrasonic Sensor

Components Details - STM LoRa Board


used to provide local computation and communications

Components Details - Servo Motor


used to lock the bin once it is full

Components Details - LCD Screen


used to show the bin’s status

Components Details - Ultrasonic Sensor


used to measure the fill level of the bin


Components Details - Load Cell and HX711

used to weight the trash
inside the bin

Energy constraints


- Low consumption
- Charge few times as possible
- Tailor duty cycle on the needs

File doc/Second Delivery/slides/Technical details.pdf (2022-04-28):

# checkBin - Technical details

## Prototype build


## Prototype build


## Wiring


## Code on the Board

Functions necessary to:


- read values from the sensors
- act using the actuators
- send data using LoRa

Image: https://docs.idew.org/project-internet-of-things/project-instructions/2-design-and-build-solution/2.2-system-model

Moreover we wrote all the logic that governs the system using the above functions.

## Logic

SENSE | ACT

COMMUNICATE


THINK


## Anomalies

Estimated weight; Sensed weight; Compare; Anomaly

## Cloud: Overview


## The Things Network


We used Lora Gateways provided by The Things Network.

These gateways allow us to easily receive packets from the boards and immediately relay them to AWS IoTCore.

## Amazon Web Services


The used AWS services are:

- IoT Core
- Lambda
- DynamoDB
- AWS Amplify

## Web Interface


To develop the web interface we used:

- services and functions hosted on AWS
- Google Maps APIs

## Web interface


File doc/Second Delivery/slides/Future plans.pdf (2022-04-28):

# checkBin - Future plans

## Technical updates for 3rd delivery


System optimisation

- Consider the possibility of using as bin identifier the DEV_EUI assigned to the board for the LoRa communication
- Study the power management API of RIOTos to understand if it can be useful for our purposes.

## Technical updates for 3rd delivery


Changes in the prototype

- Try different charging methods.
- Show the fill level as a progress bar on the oled display.
- Add a button or an NFC reader to open the bin.

## Technical updates for 3rd delivery


Changes in the web dashboard

- Websocket implementation to update the fill levels on the dashboard in real time.
- New button to delete a bin, given its identifier.

## Evaluation plans for 3rd delivery: Energy


- Energy consumption during wake-up time


- Energy consumption to activate the sensors and compute the fill level
- Energy consumption to transmit data using LoRa
- Energy consumption during sleep mode
- Energy consumption of the OLED display

## Evaluation plans for 3rd delivery: Network


- Total size of LoRa packets
- Total size of the payloads
- Total latency from the beginning of the measuring phase to the update of the web dashboard

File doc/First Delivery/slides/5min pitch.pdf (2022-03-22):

# checkBin - Concept

## The Problem


Photos: Corriere della Sera, Repubblica

## not only Images also Data


Source: AMA, Anagrafe dei rifiuti di Roma Capitale -https://www.comune.roma.it/web-resources/cms/documents/Raccolta_e_ciclo_rifiuti2018.pdf

Use of the Waste Management services in Rome

PAP: door to door collection

Stradale: on street bins collection

RD: percentage of recycled waste

## not only Images also Data


Source: https://www.agenzia.roma.it/it-settori-7-gestione_rifiuti

## not only Images also Data


Source: https://www.agenzia.roma.it/it-settori-7-gestione_rifiuti

Waste Management costs in Rome

# Our Solution


Introduction of smart bins to monitor their fill level and create a collective intelligence of the whole city status

# checkBin - Technology

## General Architecture


## Bin - Overview


## Bin - Circuit Detail


Servo Motor | Load Cell

HX711 Load Cell
Amplifier

LCD Monitor

Ultrasonic Sensor

## Energy constraints


- Low consumption
- Charge few times as possible
- Tailor duty cycle on the needs

# checkBin - Evaluation

## What we Plan to Measure for the Evaluation


- total energy consumption of the board, sensors and actuators
- total network usage on the LoRa gateway and on every single board
- final cost of the product

## What we Plan to Measure for the Evaluation

- percentage of inaccurate measurements in the bins
- difference between real fill level and measured fill level on a sample
- average filling level when bins are emptied

## Two phase plan

1. install the devices and collect data in order to create a baseline
2. enforce new policies
based on the data and
compare the outcomes to
the baseline

# checkBin - Open Impact

## Social impact data

How can we measure soft outcomes through IoT data?


Source: AMA, Anagrafe dei rifiuti di Roma Capitale -https://www.comune.roma.it/web-resources/cms/documents/Raccolta_e_ciclo_rifiuti2018.pdf

Percentage of waste diverted from disposal in Rome 2007 - 2019 (first semester)

Better precision in
gathered data

Statistics on
specific areas

# Thanks for the attention!

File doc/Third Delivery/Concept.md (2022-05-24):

# CONCEPT

The main problem of waste management in big cities is overflowing bins. This brings to garbage left on the streets, bad smells, wild animals roaming and fed up citizens. It is the consequence of an inefficient usage of the resources by garbage pickup companies, both economical and logistical (employees time and garbage trucks). As an example it happens that the usual pickup route empties not yet full bins missing the full ones.

IoT could help solve this problem without having to hire new workers nor buying new trucks, which would generate more long term expenses for the company. Through a network of intelligent devices we can monitor the fill level of every trash bin and aggregate this data to generate a centralized and complete knowledge on the real time situation of the bins in the city. Using this knowledge companies could plan efficient pickup routes based on the fill level of the bins. They could also make statistical analysis on the collected data to tailor the number of bins in each area according to the real needs.



In this way the urban welfare increases thanks to less garbage on the streets and increased usability of the bins. Another result is an improvement on how the public perceives the garbage collection company and the city administration. The flow of tourists to the city could be impacted by the usage of our system too, as a consequence of the improvement in the city reputation.

An IoT solution is required due to the intrinsic nature of the considered environment: garbage bins are spread over large areas which would be otherwise impossible to monitor. Moreover this solution can also help detect unusual filling rates due to unpredictable events.

This system could be integrated in a urban regeneration plan for a smart city. It would be useful also to measure the change in the level of awareness of the population on ecological issues, measured as percentage of waste diverted from disposal to recycling facilities during several years or in several places. Through our system we expect an increase of the citizens' involvement and responsibility and a better precision in the gathered data, regarding the quantities but also by doing statistics on specific areas of the city where there could be projects to increase awareness on ecological issues.

### Link to previous version: [Concept - Second delivery](../Second%20Delivery/Concept.md)

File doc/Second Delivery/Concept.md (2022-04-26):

# CONCEPT

The main problem of waste management in big cities is overflowing bins. This brings to garbage left on the streets, bad smells, wild animals roaming and fed up citizens. It is the consequence of an inefficient usage of the resources by garbage pickup companies, both economical and logistical (employees time and garbage trucks). As an example it happens that the usual pickup route empties not yet full bins missing the full ones.

IoT could help solve this problem without having to hire new workers nor buying new trucks, which would generate more long term expenses for the company. Through a network of intelligent devices we can monitor the fill level of every trash bin and aggregate this data to generate a centralized and complete knowledge on the real time situation of the bins in the city.
Using this knowledge companies could plan efficient pickup routes based on the fill level of the bins. They could also make statistical analysis on the collected data to tailor the number of bins in each area according to the real needs.



In this way the urban welfare increases thanks to less garbage on the streets and increased usability of the bins. Another result is an improvement on how the public perceives the garbage collection company and the city administration. The flow of tourists to the city could be impacted by the usage of our system too, as a consequence of the improvement in the city reputation.

An IoT solution is required due to the intrinsic nature of the considered environment: garbage bins are spread over large areas which would be otherwise impossible to monitor. Moreover this solution can also help detect unusual filling rates due to unpredictable events.

This system could be integrated in a urban regeneration plan for a smart city. It would be useful also to measure the change in the level of awareness of the population on ecological issues, measured as percentage of waste diverted from disposal to recycling facilities during several years or in several places. Through our system we expect an increase of the citizens' involvement and responsibility and a better precision in the gathered data, regarding the quantities but also by doing statistics on specific areas of the city where there could be projects to increase awareness on ecological issues.

### Link to previous version: [Concept - First delivery](../First%20Delivery/Concept.md)

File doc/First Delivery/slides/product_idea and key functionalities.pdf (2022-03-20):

# checkBin - Concept

# The Problem


Photos: Corriere della Sera, Repubblica

# not only Images also Data


Source: AMA, Anagrafe dei rifiuti di Roma Capitale -https://www.comune.roma.it/web-resources/cms/documents/Raccolta_e_ciclo_rifiuti2018.pdf

Use of the Waste Management services in Rome

PAP: door to door collection

Stradale: on street bins collection

RD: percentage of recycled waste

# not only Images also Data


Source: https://www.agenzia.roma.it/it-settori-7-gestione_rifiuti

# not only Images also Data


Source: https://www.agenzia.roma.it/it-settori-7-gestione_rifiuti

Waste Management costs in Rome

# Our Solution


## Introduction of smart bins to monitor their fill level and create a collective intelligence of the whole city status

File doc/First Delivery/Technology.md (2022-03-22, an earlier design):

# TECHNOLOGY

## General Architecture



***Computation***
The computation is carried both on the edge and in the cloud. Every board will compute the fill level through the data coming in from the sensors and will send only this refined value to the cloud once every hour. The cloud will generate a dashboard with a map of the city combining the data received together with the database which links every bin identifier to its location. This dashboard will be publicly available through http both to the garbage collection company and to the citizens.

## Bin Overview



Every smart bin will have an id code to be identified, which is also linked to its position. It will be equipped with:

***LoRaWAN compatible STM board***
STM32L0 Discovery kit LoRa, Sigfox, low-power wireless. The module is powered by an STM32L072CZ microcontroller and SX1276 transceiver. The transceiver features the LoRa long-range modem, providing ultra-long-range spread-spectrum communication and high interference immunity, minimizing current consumption.
In the cities there should be some LoRaWAN gateways to pick up all the signals sent by the bins.
We plan to use MQTT-SN as communication standard between the Smart bins and the LoRa gateway and MQTT as communication standard between the LoRa gateways and the Cloud provider.



***Ultrasonic sensors*** to measure occupied volume in the bin.
We use ultrasonic sensors as the main way of measuring the filling level of the bins.



***Load cells and a Load Cell Amplifier*** to measure weight of the trash in the bin.
To avoid anomalies in the data read by ultrasonic sensors we plan to also use load cells. Together with statistics based on gathered data we can compare the occupied volume in the bin and the weight to understand if there is an anomaly in the ultrasonic measure.



***LCD Monitor*** to show fill level to the citizens.
The LCD Monitor will provide information about the fill level. It will also be used to give instant feedback to the citizens using the bin. In this way they can be more involved in the process and take responsibility.



***Servo motor*** to lock the opening of the bin when it is full.



## Constraints

***Battery and Energy Consumption***
A major constraint that we have is energy consumption. We want to keep it as low as possible so that the battery can be changed a few times or none at all. During the development phase we’ll choose if we need to add some kind of solar cell or other type of charging methods. As an example we could experiment with some kind of fast charge while the trucks unload the bins. We will also carefully adjust the duty cycle to consume as little as possible, keeping in mind that:
- The LCD screen will be always on and will be updated at every change of the weight
- The servo motor will be activated only when the bin is full or recently emptied
- The ultrasonic sensor will be activated only when a change in the weight is detected
- The load cells will be always measuring weight changes
- LoRa antenna will be activated every hour to send to the cloud the current fill level

***Network***
This architecture does not have any particular network constraint. We plan to update the data on the cloud every hour, so the expected latency can be also in the order of minutes. This choice has been made considering the nature of the system which does not always need real time updates.
We’ll send to the cloud only the fill level of the bins, so the bandwidth needed by each device is minimal. Even though we take into account the great number of bins that even a small city has, the overall data transmitted is not much. Having planned a high update latency implies fewer usage of the radio that can be turned off saving energy.

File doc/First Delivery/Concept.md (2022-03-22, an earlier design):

# CONCEPT

The main problem of waste management in big cities is overflowing bins. This brings to garbage left on the streets, bad smells, wild animals roaming and fed up citizens. It is the consequence of an inefficient usage of the resources by garbage pickup companies, both economical and logistical (employees time and garbage trucks). As an example it happens that the usual pickup route empties not yet full bins missing the full ones.

IoT could help solve this problem without having to hire new workers nor buying new trucks, which would generate more long term expenses for the company. Through a network of intelligent devices we can monitor the fill level of every trash bin and aggregate this data to generate a centralized and complete knowledge on the real time situation of the bins in the city.
Using this knowledge companies could plan efficient pickup routes based on the fill level of the bins. They could also make statistical analysis on the collected data to tailor the number of bins in each area according to the real needs.



In this way the urban welfare increases thanks to less garbage on the streets and increased usability of the bins. Another result is an improvement on how the public perceives the garbage collection company and the city administration. The flow of tourists to the city could be impacted by the usage of our system too, as a consequence of the improvement in the city reputation.

An IoT solution is required due to the intrinsic nature of the considered environment: garbage bins are spread over large areas which would be otherwise impossible to monitor. Moreover this solution can also help detect unusual filling rates due to unpredictable events.

This system could be integrated in a urban regeneration plan for a smart city. It would be useful also to measure the change in the level of awareness of the population on ecological issues, measured as percentage of waste diverted from disposal to recycling facilities during several years or in several places. Through our system we expect an increase of the citizens' involvement and responsibility and a better precision in the gathered data, regarding the quantities but also by doing statistics on specific areas of the city where there could be projects to increase awareness on ecological issues.

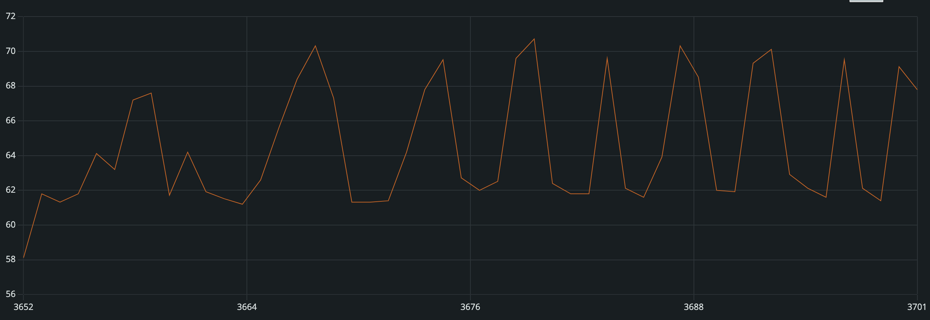
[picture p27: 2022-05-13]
img/ina_con_oled.png

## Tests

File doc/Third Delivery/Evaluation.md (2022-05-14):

# EVALUATION

## Requirements:
- The accuracy error of the fill level must be at most 10%;
- The update of the fill levels must be shown in the dashboard within 2 hours from the actual change;
- The system must be energy independent for at least a year;
- The capacity of the bin must not be reduced by more than 5% (both in weight and volume);
- The system must be compliant with the LoRa duty cycle restrictions;
- The ratio of wrong fill level measurements over total fill level measurements must be < 5%;
- The system must be able to scale up.

*These requirements were set making reasonable assumptions on the observed real world.*

## Energy Consumption
A major constraint that we have is energy consumption. We want the system to be energy independent for at least a year, considering the following energy usage:
- The OLED screen will be always on and will be updated at every change of the fill level.
- The stepper motor will be activated only when the bin is full or recently emptied.
- The sensors will be activated at the predefined intervals. The ultrasonic sensor will take three measures with a 30 seconds interval, to discard eventual measures taken while the bin was open. The load cell will also be activated to read a value.

### Replacing the OLED with a e-ink display
To further reduce the energy consumption we could replace the OLED with an e-ink display. Taking as an example the display 1.54inch e-Paper V2 - [WSH-12561](https://www.tme.eu/Document/0ca57a8ffbcd57b5bca53252eb9d6ec3/WSH-12561.pdf), we have that it consumes 0.005mA in standby and 8mA during the update phase. Considering a maximum of 10 updates every day, this display would consume roughly 0.16mAh per day which is extremely less than the 54mAh needed by the Oled display.

### Analysis on sampling frequency
One of the key aspects of the project is how often the sampling is done. Indeed, there are several possibilities:
- Continuous sampling of all the sensors: this first approach is clearly the simplest one. It allows high accuracy and responsiveness to changes but at the cost of always consuming energy. In particular, we have that keeping ON the load cell would cost 5.8mA ([datasheet](https://cdn.sparkfun.com/datasheets/Sensors/ForceFlex/hx711_english.pdf)) and keeping ON the ultrasonic would cost 3.1mA ([datasheet](https://cdn.sparkfun.com/datasheets/Sensors/Proximity/HCSR04.pdf)).
<br>This totals up to 8.9 mA. Considering a 1000mAh battery only for the sensors, they would run for 60.61 hours, which is less than 5 days. That result is clearly unacceptable for an application like ours. Indeed, the goal is to have a battery which lasts for no less than a year, also considering that it must give power also to the board and to the actuators.
<br>Moreover, continuous sensing does not make much sense in our use case. Seeing the nature of what we are measuring (i.e. people throwing away garbage), we expect random changes in the values with random intervals between them (also long periods of time in which the values do not change). This behavior clearly describes discrete events and not continuous ones, strengthening our claim of continuous sensing being unnecessary.
- Continuous sensing of one sensor and sensing of the other only when needed: this approach may be a viable solution that allows us to promptly detect changes in the environment, using the other sensor only as confirmation for the action to take. This method falls in the same shortcomings of the previous one, especially regarding the energy consumption. In particular, if we keep the ultrasonic sensor always ON with a battery of 1000 mAh, it would last for 13.44 days. This result is clearly an improvement but still not nearly enough for our goal of changing the battery not more than once a year.
<br>If keeping the ultrasonic sensor always on is not a good solution, clearly keeping on the load cell (that uses more mA than the ultrasonic sensor) is not a viable possibility. Moreover the considerations done on the nature of the environment still holds.
- Periodic sensing: this is the solution that we went for. We believe it is a good compromise between energy consumption and data availability. It is also possible to tailor the interval between measurements, during the development we choose for our application an interval of 1 hour.
<br>We came up with this value using some empirical observations and some reasoning: considering that in Rome the bins get emptied on average every 2 days and that our “fill level scale” is 0-9, we deduced that to accurately detect every level we would need to measure at least every 48/10 = 4.8 hours. Using a bigger interval we would lose accuracy in detecting when the fill level changes. Moreover we need to have a recent enough update so that the trucks can have a realist view to plan their route.
<br>A possible solution to allow trucks for better planning is to allow for sensing on request. This would imply keeping the radio always on which is unfeasible due to battery constraints. <br>In particular we chose a one hour interval because it allows us to cope with times in which there is more frequent activity (people tend to throw the garbage in defined times of the day, in the morning and in the evening). Sensing at intervals less than an hour would increase energy consumption and in normal situations we do not expect big changes in the fill level during this period of time.
<br>Assuming to use this method, we would keep both sensors ON for a few seconds every hour, which means roughly we would consume 8.9mA that corresponds to a battery lifetime of more than 9 years (assuming a 1000 mAh battery only for the sensors, one sensing every hour and 5 seconds to startup, sense and shutdown).
- We could introduce some machine learning techniques to tailor the sampling rate to the real needs. Having collected enough data on the times of the day when the bins are more used, we could know when sensing was useless (because the fill level was unchanged) and when it should have been more frequent. As a consequence we could adapt the sampling rate depending on this. We could also do a step forward by changing the sampling rate of each single bin, based on its specific needs.

### Analysis on radio usage
The second aspect that has a great impact on the consumption of energy is how often the radio is used. We came up with several possibilities:
- Transmit every new value: we would transmit data every time the sensors perform a new measurement. This solution allows to keep the radio active only a few seconds every timeout. But we do not need to know if a fill level has not changed, as for our system we are only interested in fill level changes.
- Transmit every time a fill level changes: in this case we would transmit data every time the fill level of the bin changes with regard to the previous measurement. We reduced even more the energy consumption with respect to the previous case, without losing any relevant information on the status of the bins.

The antenna will be also activated when an anomaly is detected between the fill level measure taken by the ultrasonic and the weight measured by the load cell. In that case it will be used to notify the anomaly, sending the max fill level to the cloud to notify the bin must be emptied.

In conclusion we chose to sense every hour and to send data every time there is a change in the fill level of the bin or there is an anomaly. In this way we can also be compliant with the LoRa duty cycle restrictions (in Europe they are regulated by the ETSI EN300.220 standard) and with the requirements about the latency between the change in the fill level and the result visualized in the dashboard.

### Measured energy consumption
We used a multimeter and a [INA219](https://cdn-learn.adafruit.com/downloads/pdf/adafruit-ina219-current-sensor-breakout.pdf) to measure the energy consumption of our system.

- 76.3mA Energy consumption during wake-up time
- 48.2mA + 6.1mA Energy consumption of the board + the OLED display
- \+ 8.2mA Energy consumption to activate the sensors and compute the fill level (total 62.5mA)
- \+ 34.5mA Energy consumption to transmit data using LoRa (total 88.8mA)
- \+ 90.7mA Energy consumption of the Stepper (total 145mA)

The measured consumption can be visualized in the following plot:

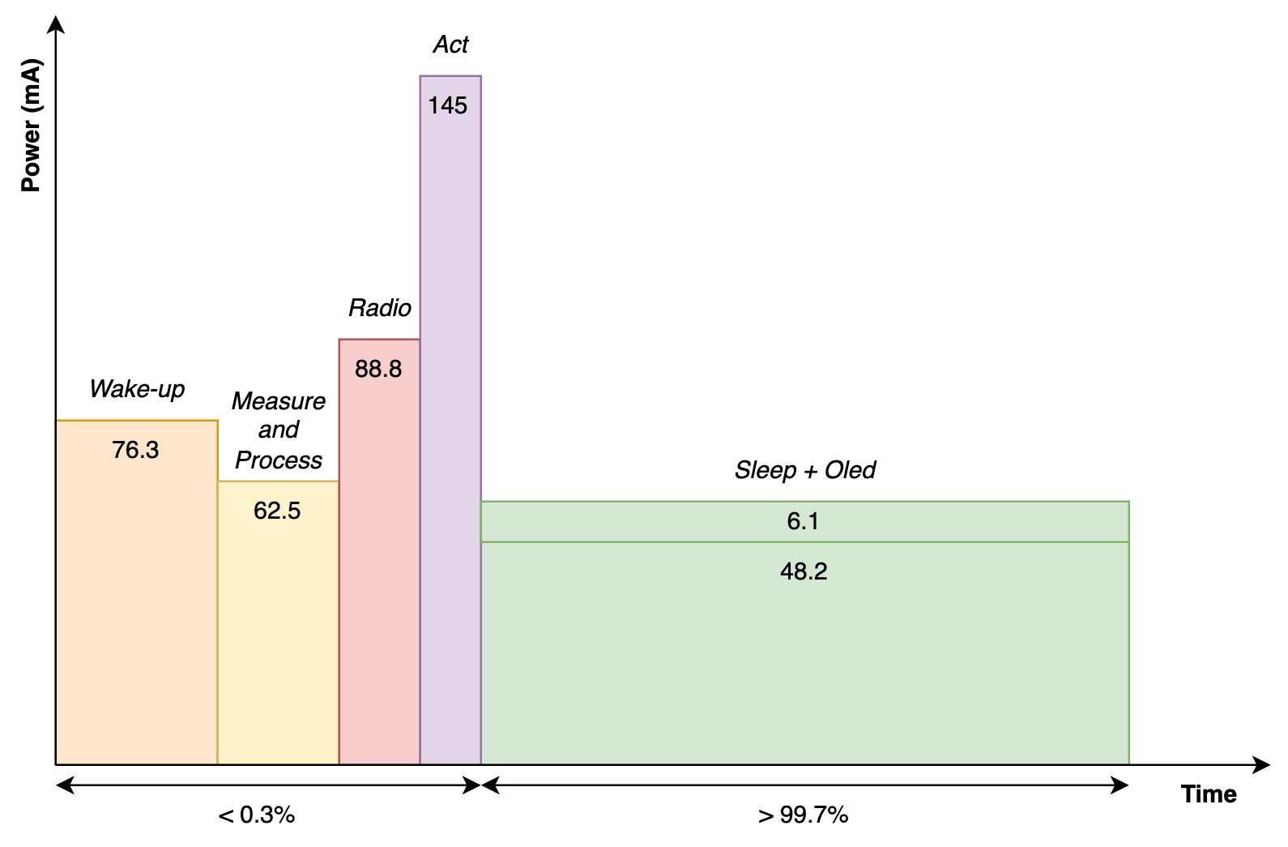
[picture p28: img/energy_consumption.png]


Through IoTLAB we measured the energy consumption during the sending of LoRa packets of the board we used. The image below shows the consumption we obtained through a monitoring profile:

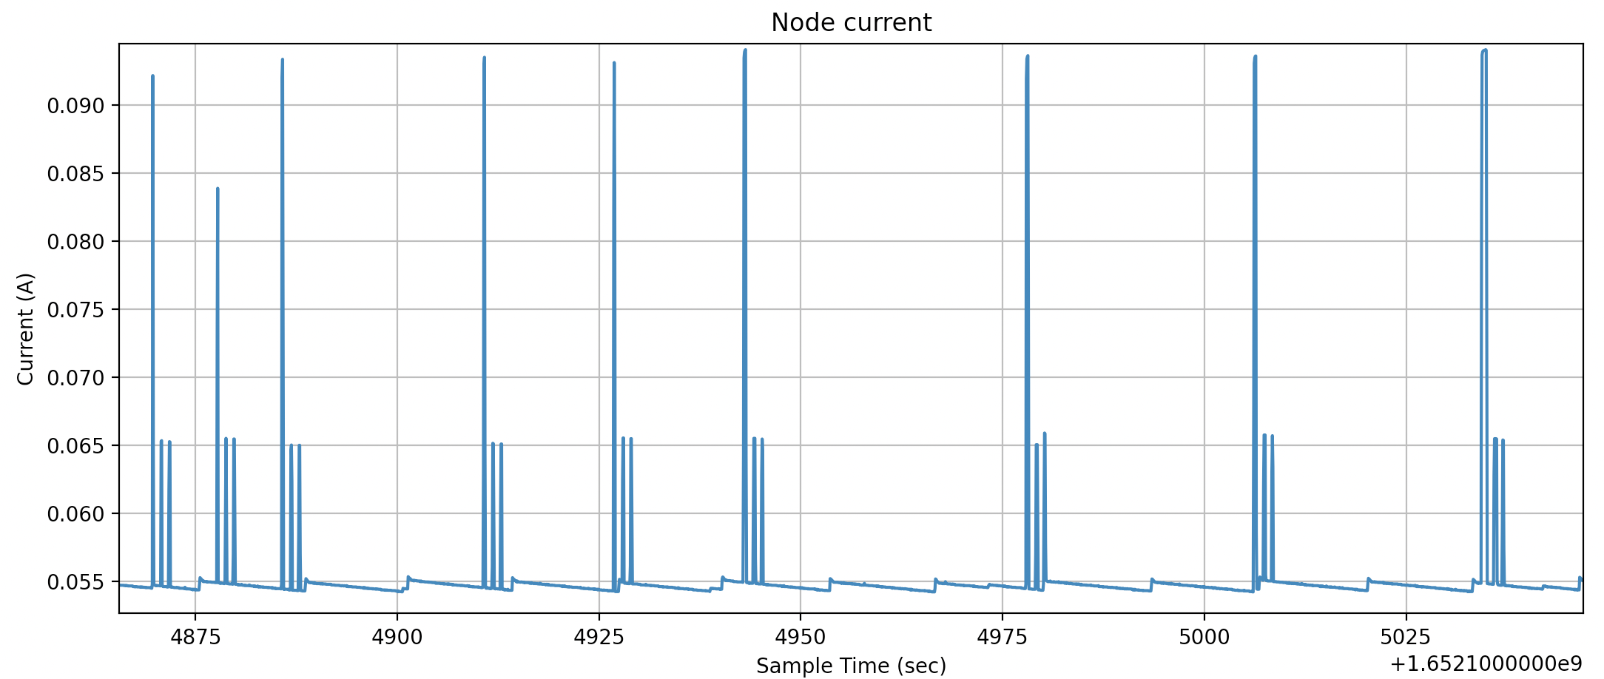
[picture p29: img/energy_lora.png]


Through the use of INA219, a Arduino UNO and the Adafruit INA219 library we obtained more precise measurements of the energy consumption of the running system:



<div>
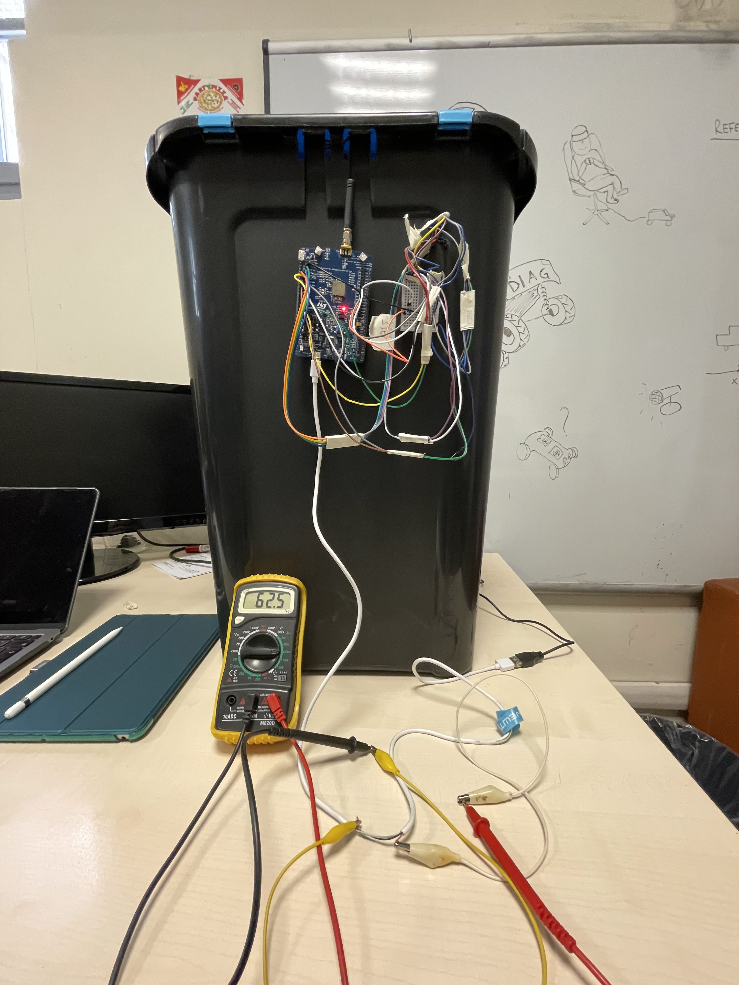
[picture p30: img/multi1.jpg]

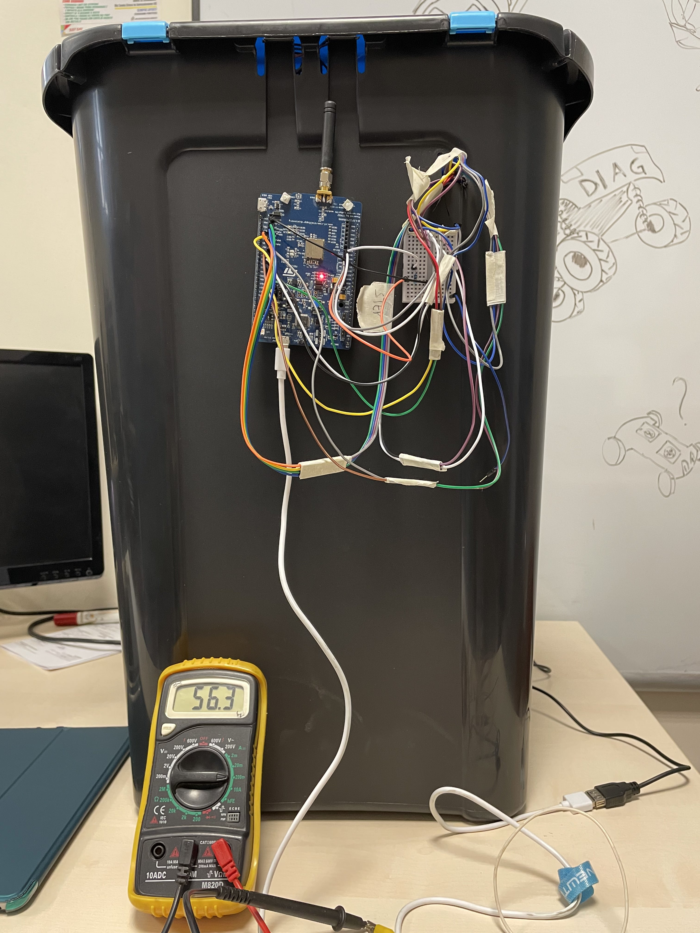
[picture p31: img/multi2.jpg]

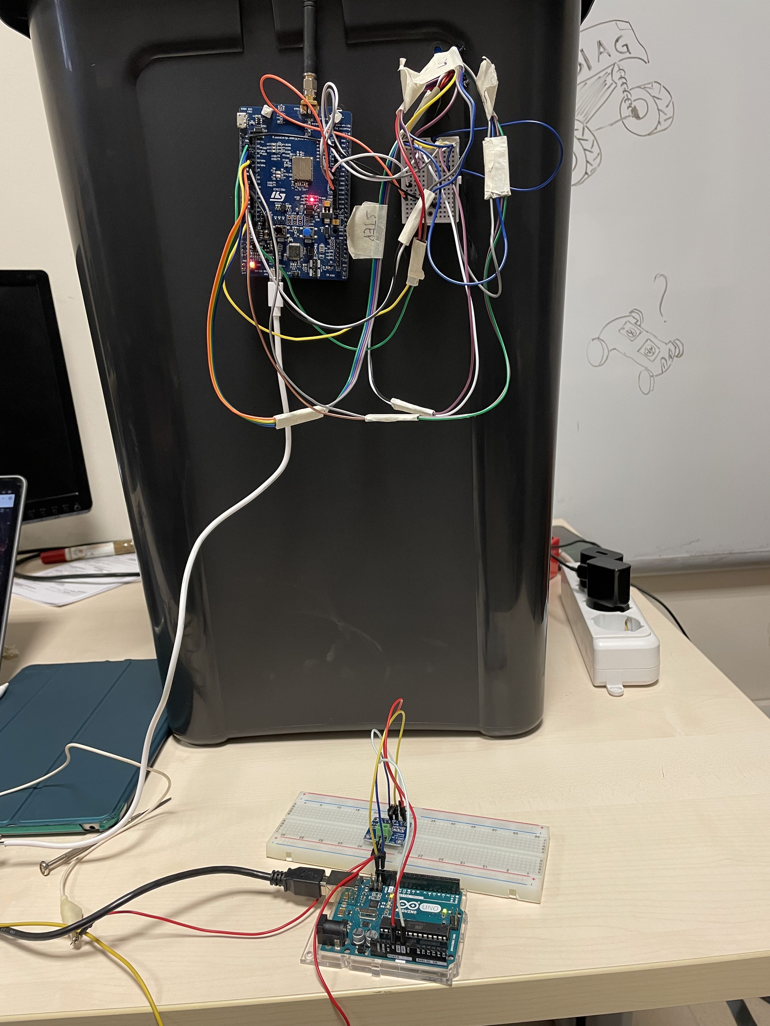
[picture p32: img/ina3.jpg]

</div>

### Battery
To power the system we must use a battery, as there is no infrastructure to keep the device plugged in. Considering the measured energy consumption and the requirements, we would need a 500A battery without using charging methods. Searching for such kind of batteries we found out their weight is not less than 35kg. Considering standard bins with a capacity of less than 500kg, that battery would violate the constraints about the reduction of capacity. Considering that conclusion we must implement some kind of charging method or loosen the constraints.

### Charging methods
We could add a solar panel to reduce the size of the needed battery and increase the lifetime. We would not have any problem finding the space to add the panel due to the size of standard bins. Considering a 5W solar power system like the [K-P105-V50-E309](https://voltaicsystems.com/5-watt-power-system/) we could obtain 7-17Wh per day according to its datasheet. Having a 5V system it could provide 1400-3400mAh per day, which are more than enough to power our device. Moreover the considered power system is also composed of a 12800mAh battery which could power our system for almost 10 days without being recharged due to environmental issues.
In regular situations this solar power system would make our device self-sufficient in terms of energy.

A different option would be using the energy provided by users pressing on the pedal to open the bin. This mechanical energy could be converted into electric energy using a dynamo. However, even if the frequency of this action is considerably high, the energy produced every time would not be able to support the consumption of the whole system. Moreover not every bin today uses this mechanism to be opened.

## Sensors precision
The precision of the fill level depends on the height of the bin. The fill level is a value between 0 and 9, computed as `fill_level = 9-(10*distance/max_distance)`. Consequently every step of the fill level will represent a height value of the trash between `fill_level*max_distance/10` and `(fill_level+1)*max_distance/10`. As a consequence we have an intrinsic error percentage of maximum 10% of the total height, which is compliant with the requirement about the accuracy of the fill level.

We measured the precision of the load cell with respect to the conversion formula we used. From the tests we have done we discovered a 2% error, which is acceptable. It is also counterbalanced by the 20% margin used when comparing weights in the code.

We conducted some tests to evaluate the accuracy of the system. 
<br> Total measurements: 40.

| Fill level from ultrasonic sensor | Total measurements | Detected anomalies | Undetected anomalies |
| --- | --- | --- | --- |
| 0 | 2 | 0 | 0 |
| 1 | 3 | 0 | 0 |
| 2 | 5 | 0 | 0 |
| 3 | 4 | 0 | 0 |
| 4 | 7 | 0 | 0 |
| 5 | 6 | 1 | 0 |
| 6 | 3 | 0 | 0 |
| 7 | 3 | 1 | 0 |
| 8 | 4 | 0 | 1 |
| 9 | 3 | 0 | 0 |
| ----------- | ----------- | ----------- | ----------- |
| Total | 40 | 2 | 1 |

Accuracy of the fill level: 92.5%. We expect the accuracy to rise with a greater sample dataset so to be compliant with the requirement about the error rate.

## Network usage

This architecture does not have any particular network constraint. As we planned to send data to the cloud only when the fill level changes or if there is an anomaly, the board should send around 10 messages every interval between two bin unloadings. This choice has been made considering the nature of the system which does not need real time updates. However, we must take into account that the great number of bins dislocated throughout the city should be supported by the gateway infrastructure.

### Considerations on Packets and Payload Size
Taking into account our implementation, we sent a LoRa message with a payload of 1 byte. Considering that a LoRa packet uses 13 bytes as header (according to the Specification 1.0.2 we are using), the total packet size is 14 bytes. Knowing that the Spreading Factor is 7, the Region is EU868 and the Bandwidth is 125kHz. Using these information and the calculator provided by The Things Network itself (you can find it [here](https://www.thethingsnetwork.org/airtime-calculator)) we obtained that the Time on Air of a packet is 43.6 ms. This is a small time period, at least with respect to the intervals we consider in our project (a bin takes measures once every hour). 

At the beginning of the project we considered sending packets with bigger payloads of 7 bytes, in this way we could also send the bin’s ID in the message. Even if the time on air would have had only a slight increase going up to 56.6 ms, a time period admissible for our situation, we opted for sending only a single byte representing the fill level. This choice was made because there is no reason to send the bin’s ID to the cloud. Indeed, the data is processed using the DevEUI, not the ID, and this information is already present in the packet by default.

### Considerations on Latency
In our use case it does not make much sense to talk about latency of the whole system, in particular if we consider that the measurement interval in a bin may be governed by a model computed using machine learning.

Instead a more relevant aspect to consider is the latency between the moment the board starts measuring and the time when the data are available to the end user. This time interval is composed of three parts:

- Time on the Board (T<sub>Board</sub>): time needed to compute the fill level and send the message; 
- Time on Air (T<sub>Air</sub>): time needed for the message to go from the board to the LoRa gateway;
- Time for Cloud Processing (T<sub>Cloud</sub>): time needed on the cloud to process the data (we also include the time needed by TTN to send the message to AWS IoT Core). 

More in details we have that: 

- T<sub>Board</sub> = T<sub>Ultrasonic</sub> + T<sub>Logic</sub> where T<sub>Ultrasonic</sub> is the time needed to perform the ultrasonics measures and T<sub>Logic</sub> is the time needed to perform the computation of the fill level and send the message.

In our case we have that:

- T<sub>Ultrasonic</sub> = 60s because the systems performs 3 measurements (one every 30 seconds) so we have them at t=0, t=30s, t=60s;
- T<sub>Logic</sub> = 0.05s empirical data tells us that the board does not take more that 50ms to compute the fill level and send it;
- T<sub>Air</sub> = 0.05s using The Things Network calculator we know that in theory the time on air is 43.6ms, to cope for some eventual delay we assumed 0.05s;
- T<sub>Cloud</sub> = 2s clearly we do not have any control over this aspect but empirical data tells us that it does not take more than 2s.

Said this we have that 
- T<sub>Board</sub> + T<sub>Air</sub> + T<sub>Cloud</sub> = T<sub>Ultrasonic</sub> + T<sub>Logic</sub> + T<sub>Air</sub> + T<sub>Cloud</sub> = 60 + 0.05 + 0.05 + 2 = 62.1s &#8771; 62s

This can be graphically seen in the image below:

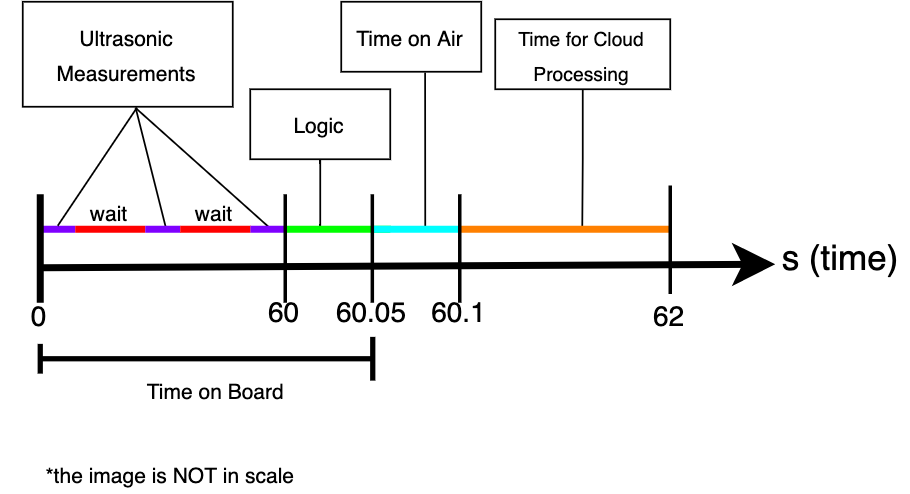
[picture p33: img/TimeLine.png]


## Scalability

To be sure our system would work in the real world environment, we also tested its scalability. We chose a block in our city and created an entity in the database for each of the bins:

<div>
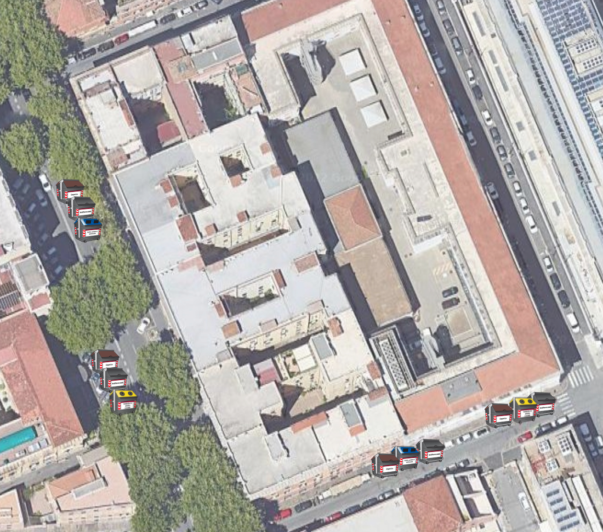
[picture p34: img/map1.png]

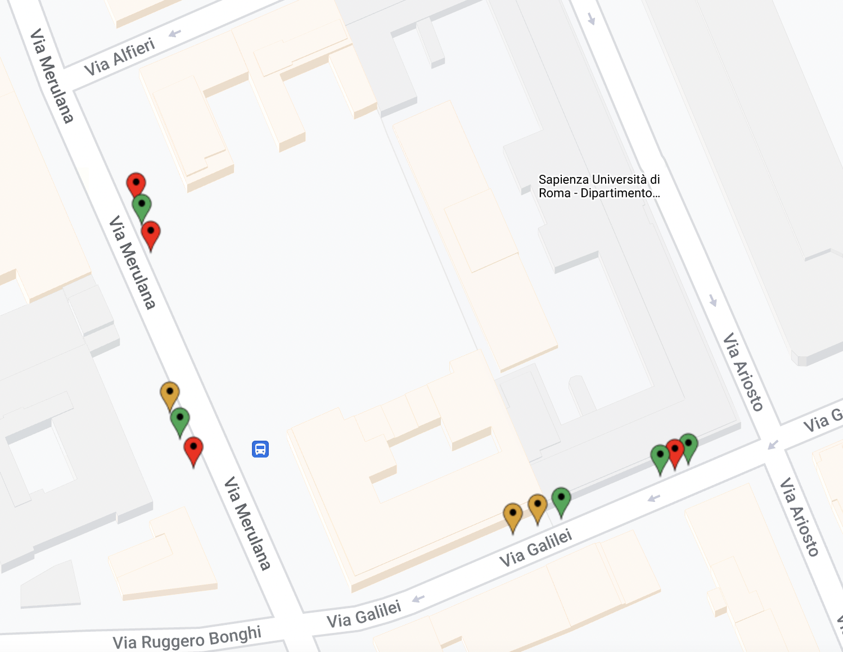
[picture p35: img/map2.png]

</div>

We used IoTLAB and created an experiment reserving 12 boards b-l072z-lrwan1 on the Saclay site. 

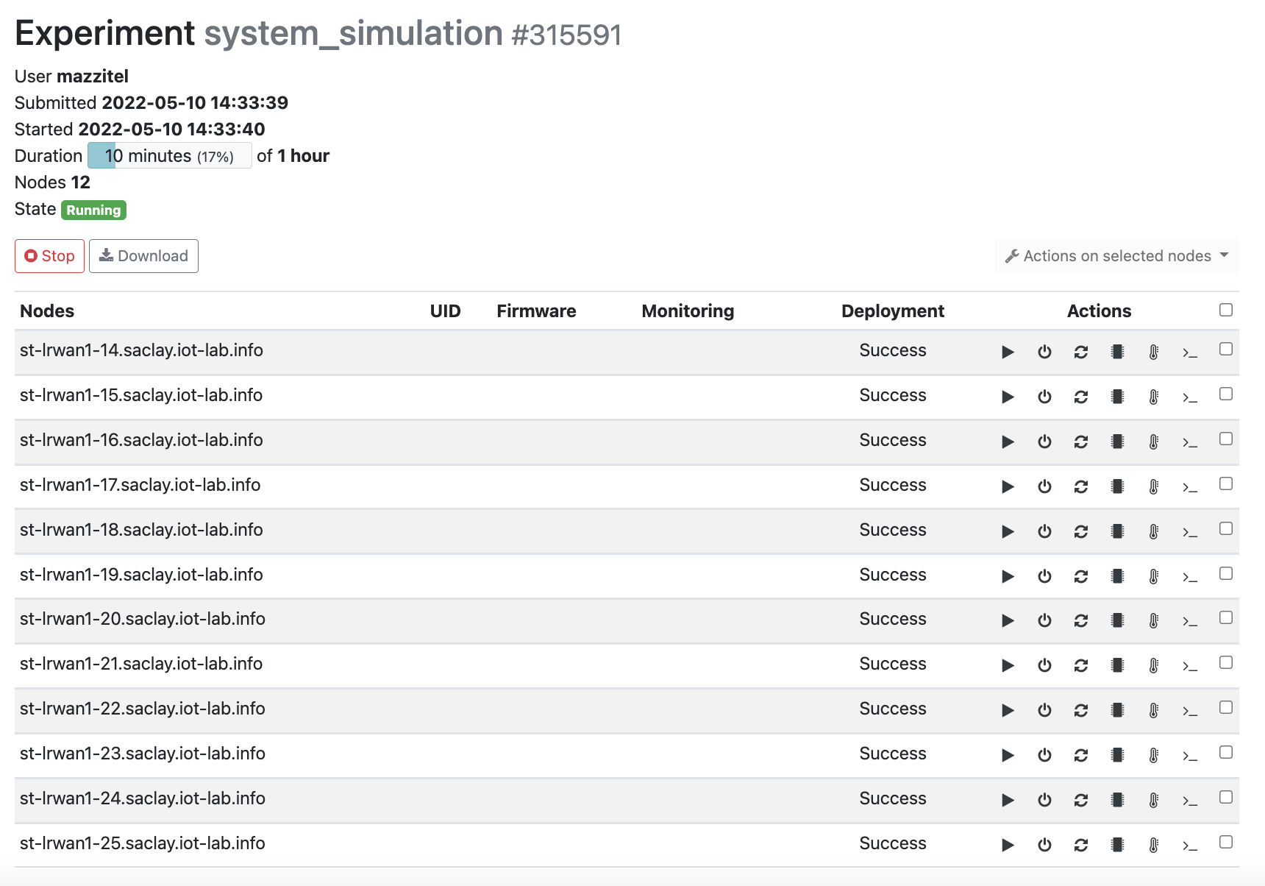
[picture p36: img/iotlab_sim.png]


We wrote some RIOT OS code to connect to the LoRa gateway, repeatedly generate random fill levels and send them to the cloud. This code was compiled and flashed on every board, using different DevEUI, AppKey and AppEUI which were linked to different bin entities in the database. The experiment ran smoothly to prove our system was capable of supporting more devices. You can find the code inside the folder "SimulationCode" of this repository.

Here you can see an extract of the recorded experiment:



From this experiment we realized we cannot use the WebSocket technology to update the dashboard every time a bin sends its fill level. Due to the high number of bins, the web dashboard could not keep up with all the updates and kept refreshing. Moreover we realized that the cloud would have had to send a high number of messages to every open dashboard. Analyzing our application, we realized that there is no need for such a feature. Indeed, the latency from the change in the fill level to the update on the cloud can be up to 1 hour. So there is no reason to implement a low latency mechanism in the dashboard. In the end we decided to force the web interface to update every 10 minute, so as not to overload the cloud with requests.

### Link to previous version: [Evaluation - Second delivery](../Second%20Delivery/Evaluation.md)

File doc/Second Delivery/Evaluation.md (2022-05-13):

# EVALUATION

## Energy Consumption
A major constraint that we have is energy consumption. We want the battery to last for at least a year. Anyway, given the size of standard city bins, we are not too concerned about the size of the battery. During the next development phase we’ll also choose if we need to add some kind of solar cell or other type of charging methods. As an example we could experiment with some kind of fast charge while the trucks unload the bins.
- The OLED screen will be always on and will be updated at every change of the fill level.
- The stepper motor will be activated only when the bin is full or recently emptied.
- The sensors will be activated at the predefined intervals. The ultrasonic sensor will take three measures with a 30 seconds interval, to discard eventual measures taken while the bin was open. The load cell will also be activated to read a value.

### Analysis on sampling frequency:
One of the key aspects of the project is how often the sampling is done. Indeed, there are several possibilities:
- Continuous sampling of all the sensors: this first approach is clearly the simplest one. It allows high accuracy and responsiveness to changes but at the cost of always consuming energy. In particular, we have that keeping ON the load cell would cost 1.5mA ([datasheet](https://cdn.sparkfun.com/datasheets/Sensors/ForceFlex/hx711_english.pdf)) and keeping ON the ultrasonic would cost 15mA ([datasheet](https://cdn.sparkfun.com/datasheets/Sensors/Proximity/HCSR04.pdf)).
<br>This totals up to 16.5 mA. Considering a 1000mAh battery only for the sensors, they would run for 60.61 hours, which is almost 3 days. That result is clearly unacceptable for an application like ours. Indeed, the goal is to have a battery which lasts for no less than a year, also considering that it must give power also to the board and to the actuators.
<br>Moreover, continuous sensing does not make much sense in our use case. Seeing the nature of what we are measuring (i.e. people throwing away garbage), we expect random changes in the values with random intervals between them (also long periods of time in which the values do not change). This behavior clearly describes discrete events and not continuous ones, strengthening our claim of continuous sensing being unnecessary.
- Continuous sensing of one sensor and sensing of the other only when needed: this approach may be a viable solution that allows us to promptly detect changes in the environment, using the other sensor only as confirmation for the action to take. This method falls in the same shortcomings of the previous one, especially regarding the energy consumption. In particular, if we keep the load cell always ON with a battery of 1000 mAh, it would last for 27.75 days. This result is clearly an improvement but still not nearly enough for our goal of changing the battery not more than once a year.
<br>If keeping the load cell always on is not a good solution, clearly keeping on the ultrasonic sensor (that uses 10 times more mA than the load cell) is not a viable possibility. Moreover the considerations done on the nature of the environment still holds.
- Periodic sensing: this is the solution that we went for. We believe it is a good compromise between energy consumption and data availability. It is also possible to tailor the interval between measurements, during the development we choose for our application an interval of 1 hour.
<br>We came up with this value using some empirical observations and some reasoning: considering that in Rome the bins get emptied on average every 2 days and that our “fill level scale” is 0-9, we deduced that to accurately detect every level we would need to measure at least every 48/10 = 4.8 hours. Using a bigger interval we would lose accuracy in detecting when the fill level changes. Moreover we need to have a recent enough update so that the trucks can have a realist view to plan their route.
<br>A possible solution to allow trucks for better planning is to allow for sensing on request. This would imply keeping the radio always on which is unfeasible due to battery constraints. <br>In particular we chose a one hour interval because it allows us to cope with times in which there is more frequent activity (people tend to throw the garbage in defined times of the day, in the morning and in the evening). Sensing at intervals less than an hour would increase energy consumption and in normal situations we do not expect big changes in the fill level during this period of time.
<br>Assuming to use this method, we would keep both sensors ON for a few seconds every hour, which means roughly we would consume 16.5mA that corresponds to a battery lifetime of almost 5 years (assuming a 1000 mAh battery only for the sensors, one sensing every hour and 5 seconds to startup, sense and shutdown).
- We could introduce some machine learning techniques to tailor the sampling rate to the real needs. Having collected enough data on the times of the day when the bins are more used, we could know when sensing was useless (because the fill level was unchanged) and when it should have been more frequent. As a consequence we could adapt the sampling rate depending on this. We could also do a step forward by changing the sampling rate of each single bin, based on its specific needs.

### Analysis on radio usage: 
The second aspect that has a great impact on the consumption of energy is how often the radio is used. We came up with several possibilities:
- Transmit every new value: we would transmit data every time the sensors perform a new measurement. This solution allows to keep the radio active only a few seconds every timeout. But we do not need to know if a fill level has not changed, as for our system we are only interested in fill level changes.
- Transmit every time a fill level changes: in this case we would transmit data every time the fill level of the bin changes with regard to the previous measurement. We reduced even more the energy consumption with respect to the previous case, without losing any relevant information on the status of the bins.

The antenna will be also activated when an anomaly is detected between the fill level measure taken by the ultrasonic and the weight measured by the load cell. In that case it will be used to notify the anomaly, sending the max fill level to the cloud to notify the bin must be emptied.

In conclusion we choose to sense every hour and to send data every time there is a change in the fill level of the bin or there is an anomaly.

## Sensors precision
The precision of the fill level depends on the height of the bin. The fill level is a value between 0 and 9, computed as `fill_level = 9-(10*distance/max_distance)`. Consequently every step of the fill level will represent a height value of the trash between `fill_level*max_distance/10` and `(fill_level+1)*max_distance/10`. As a consequence we have an intrinsic error percentage of maximum 10% of the total height, which is tolerable for our application.

We measured the precision of the load cell with respect to the conversion formula we used. From the tests we have done we discovered a 2% error, which is acceptable. It is also counterbalanced by the 20% margin used when comparing weights in the code.

We conducted some tests to evaluate the accuracy of the system. 
<br> Total measurements: 40.

| Fill level from ultrasonic sensor | Total measurements | Detected anomalies | Undetected anomalies |
| --- | --- | --- | --- |
| 0 | 2 | 0 | 0 |
| 1 | 3 | 0 | 0 |
| 2 | 5 | 0 | 0 |
| 3 | 4 | 0 | 0 |
| 4 | 7 | 0 | 0 |
| 5 | 6 | 1 | 0 |
| 6 | 3 | 0 | 0 |
| 7 | 3 | 1 | 0 |
| 8 | 4 | 0 | 1 |
| 9 | 3 | 0 | 0 |
| ----------- | ----------- | ----------- | ----------- |
| Total | 40 | 2 | 1 |

Accuracy of the fill level: 92.5%. We expect the accuracy to rise with a greater sample dataset.

## Network usage

This architecture does not have any particular network constraint. As we planned to send data to the cloud only when the fill level changes or if there is an anomaly, the board should send around 10 messages every interval between two bin unloadings. This choice has been made considering the nature of the system which does not need real time updates.

The great number of bins dislocated throughout the city should be supported by the gateway infrastructure.

The latency measured using the prototype from the sending to the update of the web dashboard is less than 2 seconds, which is more than enough for our use case.

We’ll send to the cloud only the fill level of the bins and the bin identifier, so the bandwidth needed by each device is minimal. The size of the payload sent using LoRa to the cloud is less than 10bytes (1 for the fill level, 1 for the separator character and up to 8 for the bin identifier). To reduce the network usage we could also remove the bin identifier from the message, using the DEV_EUI assigned to the board as bin identifier.

We plan to test the whole system using a simulated environment provided by IoT_LAB. In this way we will also analyze the scalability of our system.

### Link to previous version: [Evaluation - First delivery](../First%20Delivery/Evaluation.md)

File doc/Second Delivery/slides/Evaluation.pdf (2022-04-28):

# checkBin - Evaluation

# Energy consumption

- Sensors: ultrasonic and
load cell
- Actuators: OLED display
and stepper motor
- Board
- Radio

## Analysis on sampling frequency

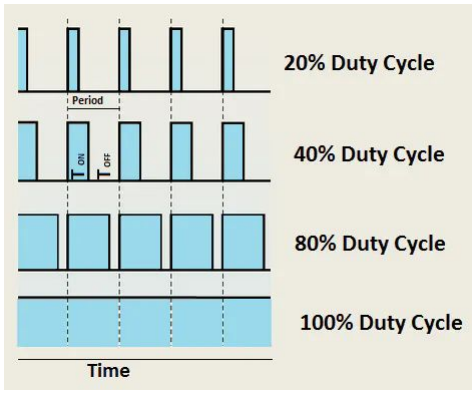
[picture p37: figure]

- Continuous sampling of all the sensors
- Continuous sampling of one sensor and sensing of the other only when needed
- Periodic sensing

## Analysis on radio usage

one is computed; - Transmit the fill level every time it changes with respect to the last measured one

- Transmit the fill level every time a new


## Sensors precision


Ultrasonic sensor

Fill level → value between 0 and 9

Fill level step represents a range of size bin_height/10

Error percentage of the fill level: max 10% of the total height

Load cell

Conversion formula:

(base_value - measured_value)/0.104

Error: ~2%

## Accuracy of the system


## Network

- Bandwidth: size of the payload is less than 10 bytes
- Latency: from the sending of the message to the update in the dashboard is less than 2 seconds
- Gateway infrastructure: must cover all the bins


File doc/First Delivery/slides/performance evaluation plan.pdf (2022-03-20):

# checkBin - Evaluation

## What we Plan to Measure for the Evaluation


- total energy consumption of the board, sensors and actuators
- total network usage on the LoRa gateway and on every single board
- final cost of the product

## What we Plan to Measure for the Evaluation

- percentage of inaccurate measurements in the bins
- difference between real fill level and measured fill level on a sample
- average filling level when bins are emptied

## Tools that will be used


## Two phase plan

1. install the devices and measure data in order to
create a baseline
2. enforce new policies
based on the data and
compare the outcomes to
the baseline

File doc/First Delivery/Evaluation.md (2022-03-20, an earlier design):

# EVALUATION

To evaluate the performance of the system we expect to measure several factors:
- total energy consumption of the board, sensors and actuators
- total network usage on the LoRa gateway and on every single board
- final cost of the product
- percentage of inaccurate measurements in the bins
- difference between real fill level and measured fill level on a sample
- average fill level when bins are emptied

We’ll use simulation tools such as IoTLab, prototyping and measures taken directly on the field.

We will measure the effectiveness of the system through a two phase plan:
1. In the first phase we’ll use the device only to collect data and create a baseline.
2. In the second phase we’ll measure the same values after the company has changed its mode of operation using the data we provide. We will then compare this outcome with the baseline.

As an example we could apply this method to know how many bins were emptied before it was really needed or to measure the logistic costs before and after the changes (in terms of petrol used, needed vehicles and workers).

We will also use performance evaluation on energy consumption during the development phase to decide whether to use some sort of charging system for the battery.

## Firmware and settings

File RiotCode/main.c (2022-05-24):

#include <stdio.h>
#include <string.h>
#include "periph/gpio.h"
#include "xtimer.h"
#include "thread.h"
#include "cpu.h"
#include "board.h"
#include "fmt.h"
#include "net/loramac.h"
#include "semtech_loramac.h"
#include "periph/i2c.h"
#include "timex.h"
#include "ztimer.h"
#include "u8g2.h"
#include "u8x8_riotos.h"
#include "main.h"

#define CYCLE_TIMEOUT 1
#define MEASURE_TIMEOUT 2
#define ZERO_LOAD_CELL 8498

//Specific weights g/m3
#define SW_PLASTIC 25000
#define SW_METAL 100000
#define SW_GLASS 200000
#define SW_PAPER 30000
#define SW_FOOD 250000
#define SW_MIXED 85000

#ifndef WASTE_TYPE
#define SW SW_MIXED
#elif WASTE_TYPE == WASTE_TYPE_PLASTIC
#define SW SW_PLASTIC
#elif WASTE_TYPE == WASTE_TYPE_METAL
#define SW SW_METAL
#elif WASTE_TYPE == WASTE_TYPE_GLASS
#define SW SW_GLASS
#elif WASTE_TYPE == WASTE_TYPE_PAPER
#define SW SW_PAPER
#elif WASTE_TYPE == WASTE_TYPE_FOOD
#define SW SW_FOOD
#elif WASTE_TYPE == WASTE_TYPE_MIXED
#define SW SW_MIXED
#endif

#ifndef DEVEUI
#error "MISSING LoRa DEVEUI"
#endif
#ifndef APPEUI
#error "MISSING LoRa APPEUI"
#endif
#ifndef APPKEY
#error "MISSING LoRa APPKEY"
#endif
#ifndef MAX_DISTANCE
#error "MISSING Max_Distance"
#endif
#ifndef AREA
#error "MISSING Area"
#endif

//ultrasonic sensor
gpio_t trigger_pin = GPIO_PIN(PORT_A, 9); //D8 -> trigger
gpio_t echo_pin = GPIO_PIN(PORT_B, 12); //D9 -> echo
uint32_t echo_time;
uint32_t echo_time_start;

//load cell
gpio_t sck = GPIO_PIN(PORT_B, 14); //D12 -> SCK
gpio_t dt = GPIO_PIN(PORT_B, 15); //D11 -> DT

//stepper motor
gpio_t pin_step_1 = GPIO_PIN(PORT_B, 5); //D4 -> IN1
gpio_t pin_step_2 = GPIO_PIN(PORT_B, 7); //D5 -> IN2
gpio_t pin_step_3 = GPIO_PIN(PORT_B, 13); //D3 -> IN3
gpio_t pin_step_4 = GPIO_PIN(PORT_A, 8); //D7 -> IN4
int stepper_status;

//display pin SDA D14 and SCK D15
#define TEST_OUTPUT_I2C 4
u8g2_t u8g2;
u8x8_riotos_t user_data =
{
    .device_index = TEST_I2C,
    .pin_cs = TEST_PIN_CS,
    .pin_dc = TEST_PIN_DC,
    .pin_reset = TEST_PIN_RESET,
};
char fill_bar[25];

//button
gpio_t pin_button = GPIO_PIN(PORT_A, 10); //D2
char stack[THREAD_STACKSIZE_MAIN];

//LoRa
extern semtech_loramac_t loramac;

void echo_cb(void* arg){ //callback function - ultrasonic sensor
	int val = gpio_read(echo_pin);
	uint32_t echo_time_stop;

    (void) arg;

	if(val){
		echo_time_start = xtimer_now_usec();
	}
    else{
		echo_time_stop = xtimer_now_usec();
		echo_time = echo_time_stop - echo_time_start;
	}
}

int read_distance(void){ //ultrasonic sensor
	echo_time = 0;
	gpio_clear(trigger_pin);
	xtimer_usleep(20);
	gpio_set(trigger_pin);
	xtimer_msleep(100);
	return echo_time/58;
}

void set_stepper(int flag){ //stepper motor
    int steps = 0;
    int count = 500;
    while (count) {
        switch(steps) {
            case 0:
            gpio_clear(pin_step_1);
            gpio_clear(pin_step_2);
            gpio_clear(pin_step_3);
            gpio_set(pin_step_4);
            break;
            case 1:
            gpio_clear(pin_step_1);
            gpio_clear(pin_step_2);
            gpio_set(pin_step_3);
            gpio_clear(pin_step_4);
            break;
            case 2:
            gpio_clear(pin_step_1);
            gpio_set(pin_step_2);
            gpio_clear(pin_step_3);
            gpio_clear(pin_step_4);
            break;
            case 3:
            gpio_set(pin_step_1);
            gpio_clear(pin_step_2);
            gpio_clear(pin_step_3);
            gpio_clear(pin_step_4);
            break;
        } 
        steps=steps+flag;
        xtimer_msleep(4);
        if (steps>3){
            steps=0;
        }
        if (steps<0){
            steps=3;
        }
        count--;
    }
    gpio_clear(pin_step_1);
    gpio_clear(pin_step_2);
    gpio_clear(pin_step_3);
    gpio_clear(pin_step_4);

}

unsigned long read_weight(void){ //load cell
    unsigned long val;
    val=0;
    for (int i=0; i<24; i++){
        gpio_set(sck);
        xtimer_usleep(20);
        val = val<<1;
        gpio_clear(sck);
        if (gpio_read(dt)>0){
            val++;
        }
    }
    gpio_set(sck);
    xtimer_usleep(20);
    val = val ^ 0x800000;
    gpio_clear(sck);
    val=val/1000;
    if (val>ZERO_LOAD_CELL){
        val=ZERO_LOAD_CELL;
    }
    int grams = (ZERO_LOAD_CELL-val)/0.104;
    if (grams<=0) return 0;
    else return grams;
}


void write_oled(char* message, int level){ //Display
    for (int i=2; i<12; i++){
        if (i-2<=level){
            fill_bar[i*2-2]='|';
            fill_bar[i*2-1]='|';
        }
        else{
            fill_bar[i*2-2]='.';
            fill_bar[i*2-1]='.';
        }
    }
    u8g2_FirstPage(&u8g2);
    do {
        u8g2_SetDrawColor(&u8g2, 1);
        u8g2_SetFont(&u8g2, u8g2_font_helvB12_tf);
        u8g2_DrawStr(&u8g2, 12, 22, message);
        u8g2_DrawStr(&u8g2, 12, 50, fill_bar);
    } while (u8g2_NextPage(&u8g2));
}

void *open_button(void *arg) {
    (void) arg;
    while(true){
        if(gpio_read(pin_button)>0 && stepper_status==1){
            set_stepper(-1);
            stepper_status=0;
        }
        xtimer_msleep(200);
    }
    return NULL;
}

int loramac_setup(char *deui, char *aeui, char *akey, char *xdr){ //LoRa setup
    uint8_t deveui[LORAMAC_DEVEUI_LEN];
    uint8_t appeui[LORAMAC_APPEUI_LEN];
    uint8_t appkey[LORAMAC_APPKEY_LEN];
    uint8_t dr;
    uint8_t join_type;

    fmt_hex_bytes(deveui, deui);
    fmt_hex_bytes(appeui, aeui);
    fmt_hex_bytes(appkey, akey);
    dr = atoi(xdr);

    semtech_loramac_set_deveui(&loramac, deveui);
    semtech_loramac_set_appeui(&loramac, appeui);
    semtech_loramac_set_appkey(&loramac, appkey);
    semtech_loramac_set_dr(&loramac, dr);

    join_type = LORAMAC_JOIN_OTAA;

    semtech_loramac_join(&loramac, join_type);

    return 0;
}

int loramac_send(char *message){ //LoRa send
    uint8_t cnf = CONFIG_LORAMAC_DEFAULT_TX_MODE;
    uint8_t port = CONFIG_LORAMAC_DEFAULT_TX_PORT;

    semtech_loramac_set_tx_mode(&loramac, cnf);
    semtech_loramac_set_tx_port(&loramac, port);

    semtech_loramac_send(&loramac,(uint8_t *)message, strlen(message));
    
    return 0;
}

void components_init(void){ //initialize all pins and components
    gpio_init(sck, GPIO_OUT);
    gpio_init(dt, GPIO_IN);

    gpio_init(trigger_pin, GPIO_OUT);
    gpio_init_int(echo_pin, GPIO_IN, GPIO_BOTH, &echo_cb, NULL);

    read_distance();

    gpio_init(pin_step_1, GPIO_OUT);
    gpio_init(pin_step_2, GPIO_OUT);
    gpio_init(pin_step_3, GPIO_OUT);
    gpio_init(pin_step_4, GPIO_OUT);
    stepper_status=0; //0 open, 1 closed

    TEST_DISPLAY(&u8g2, U8G2_R0, u8x8_byte_hw_i2c_riotos, u8x8_gpio_and_delay_riotos);
    u8g2_SetUserPtr(&u8g2, &user_data);
    u8g2_SetI2CAddress(&u8g2, TEST_ADDR);
    u8g2_InitDisplay(&u8g2);
    u8g2_SetPowerSave(&u8g2, 0);
    sprintf(fill_bar,"0 .................... 9");

    gpio_init(pin_button, GPIO_IN);
    thread_create(stack, sizeof(stack),
                    THREAD_PRIORITY_MAIN - 1,
                    THREAD_CREATE_STACKTEST,
                    open_button,
                    NULL, "open_button");

    char *deveui = DEVEUI;
    char *appeui = APPEUI;
    char *appkey = APPKEY;
    char *dr = "5";
    loramac_setup(deveui, appeui, appkey, dr);
}

int main(void){
    
    components_init();
    int distance_1;
    int distance_2;
    int distance_3;
    int distance;
    int fill_level=0;
    unsigned long weight;
    int estimated_weight;
    float max_weight = AREA*MAX_DISTANCE*0.01*SW;
    int old_fill_level;
    char st_fill[2];
    char msg[8];

    while (true){
        distance=0;

        distance_1 = read_distance();
        xtimer_sleep(MEASURE_TIMEOUT);
        distance_2 = read_distance();
        xtimer_sleep(MEASURE_TIMEOUT);
        distance_3 = read_distance();

        if (distance_1-distance_2<3 && distance_2-distance_1<3){
            distance=distance_1;
        }
        else if(distance_2-distance_3<3 && distance_3-distance_2<3){
            distance=distance_2;
        }
        else if(distance_1-distance_3<3 && distance_3-distance_1<3){
            distance=distance_3;
        }
        
        if (distance>=MAX_DISTANCE){
            distance=MAX_DISTANCE-1;
        }

        old_fill_level = fill_level;
        fill_level = 9-(10*distance/MAX_DISTANCE);

        weight = read_weight();

        estimated_weight = (MAX_DISTANCE-distance)*0.01*AREA*SW;
        
        printf("distance: %d, weight: %lu, estimated_weigth: %d, fill_level: %d\n", distance, weight, estimated_weight, fill_level);
        
        if (weight>(1.2*max_weight) && fill_level<8){ //leave the bin open and set fill level to 9 (20% margin)
            if (stepper_status==1){
                set_stepper(-1);
                stepper_status=0;
            }
            sprintf(st_fill, "%d", 9);
            loramac_send(st_fill);

            sprintf(msg, "Fill level: %d", fill_level);
            write_oled(msg, fill_level);

            puts("1. weight exceed but fill level low");
        }
        else if (old_fill_level!=fill_level){
            sprintf(st_fill, "%d", fill_level);
            loramac_send(st_fill);

            sprintf(msg, "Fill level: %d", fill_level);
            write_oled(msg, fill_level);

            puts("2. fill level changed");

            if (fill_level>=8 && weight<(0.8*estimated_weight)){ //leave the bin open (20% margin)
                if (stepper_status==1){
                    set_stepper(-1);
                    stepper_status=0;
                }
                puts("3. weight low but fill level high");
            }
            else if (fill_level>=8){ //close the bin
                if (stepper_status==0){
                    set_stepper(1);
                    stepper_status=1;
                }
                puts("4. fill level high");
            }
            else if (stepper_status==1){
                puts("5. open");
                set_stepper(-1);
                stepper_status=0;
            }
        }

        xtimer_sleep(CYCLE_TIMEOUT);
    }

    return 0;
}

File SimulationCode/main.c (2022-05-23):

//including needed libraries
#include <stdio.h>
#include <string.h>

#include "fmt.h"

#include "net/loramac.h"
#include "semtech_loramac.h"

#include "xtimer.h"
#include "random.h"

#define MAX 10
#define MIN 0
extern semtech_loramac_t loramac;

//Utility Functions for lora
int loramac_setup(char *deui, char *aeui, char *akey, char *xdr){
    uint8_t deveui[LORAMAC_DEVEUI_LEN];
    uint8_t appeui[LORAMAC_APPEUI_LEN];
    uint8_t appkey[LORAMAC_APPKEY_LEN];
    uint8_t dr;
    uint8_t join_type;

    fmt_hex_bytes(deveui, deui);
    fmt_hex_bytes(appeui, aeui);
    fmt_hex_bytes(appkey, akey);
    dr = atoi(xdr);

    semtech_loramac_set_deveui(&loramac, deveui); // setting deveui
    semtech_loramac_set_appeui(&loramac, appeui); // setting appeui
    semtech_loramac_set_appkey(&loramac, appkey); // setting appkey
    semtech_loramac_set_dr(&loramac, dr);         // setting dr

    // End Setup
    // Start Join

    join_type = LORAMAC_JOIN_OTAA;
    switch (semtech_loramac_join(&loramac, join_type))
    {
    case SEMTECH_LORAMAC_DUTYCYCLE_RESTRICTED:
        puts("Cannot join: dutycycle restriction");
        return 1;
    case SEMTECH_LORAMAC_BUSY:
        puts("Cannot join: mac is busy");
        return 1;
    case SEMTECH_LORAMAC_JOIN_FAILED:
        puts("Join procedure failed!");
        return 1;
    case SEMTECH_LORAMAC_ALREADY_JOINED:
        puts("Warning: already joined!");
        return 1;
    case SEMTECH_LORAMAC_JOIN_SUCCEEDED:
        puts("Join procedure succeeded!");
        break;
    default: /* should not happen */
        break;
    }
    puts("SetUp and Join Successful");
    // End Join Procedure

    return 0;
}

int loramac_send(char *message)
{
    uint8_t cnf = CONFIG_LORAMAC_DEFAULT_TX_MODE;  /* Default: confirmable */
    uint8_t port = CONFIG_LORAMAC_DEFAULT_TX_PORT; /* Default: 2 */

    semtech_loramac_set_tx_mode(&loramac, cnf);
    semtech_loramac_set_tx_port(&loramac, port);


    switch (semtech_loramac_send(&loramac,(uint8_t *)message, strlen(message)))
    {
    case SEMTECH_LORAMAC_NOT_JOINED:
        puts("Cannot send: not joined");
        return 1;

    case SEMTECH_LORAMAC_DUTYCYCLE_RESTRICTED:
        puts("Cannot send: dutycycle restriction");
        return 1;

    case SEMTECH_LORAMAC_BUSY:
        puts("Cannot send: MAC is busy");
        return 1;

    case SEMTECH_LORAMAC_TX_ERROR:
        puts("Cannot send: error");
        return 1;

    case SEMTECH_LORAMAC_TX_CNF_FAILED:
        puts("Fail to send: no ACK received");
        return 1;
    }
    puts("Message Sent");
    return 0;
}

//function that randomly generates fill_level
int fill_level_generator(int previous){        
        
        if(previous == 9){
            previous = 0;
            return previous;
        }
        
        int r_norm = random_uint32_range(MIN, MAX);
        if(r_norm == 0)r_norm+=1;
        
        if(r_norm + previous > 9)previous=9;
        else{
            previous += r_norm;
        }
        printf("RANDOM NUMBER: %d\n", r_norm);
        return previous;
    
}


int main(void){

//set up lora parameters
    char *deveui = "0000000000000000";
    char *appeui = "0000000000000000";
    char *appkey = "00000000000000000000000000000000";
    char *dr = "5";

    loramac_setup(deveui, appeui, appkey, dr);

   int previous = 0;
   char msg[10];
   char *m = msg;

   random_init(1); //RNG initialization
   //loop that keep generating random fill_levels
   while(1){
	printf("BEFORE\n");
	previous = fill_level_generator(previous);
	sprintf(msg, "%d", previous);
	
	loramac_send(m);
	printf("SEND: %s\n", msg);
	printf("Sent: %s\n", m);

	printf("AFTER--\n");
	xtimer_sleep(20);
}

    return 0;
}

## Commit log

2022-04-22 create directory for lora material
2022-04-23 pin images
2022-04-23 upload yellow- pin image
2022-04-24 measure ultrasonic fixed
2022-04-26 upload circuit v2
2022-05-03 update fritzing
    [circuit.fzz]
2022-05-03 thread button + oled bar
2022-05-03 chenage button pin
2022-05-10 fritzing + remove bin id
    [circuit.fzz]
